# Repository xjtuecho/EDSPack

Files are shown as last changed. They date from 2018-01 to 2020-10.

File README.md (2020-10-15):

[English User Manual](UserManual_EN.md)

[English Release Notes](ReleaseNotes_EN.md)

# PDF用户手册下载

- [EDSPack用户手册v18.10.31](DOC/EDSPack用户手册v18.10.31.pdf)

- [STOPack用户手册v19.1.22](DOC/STOPack用户手册v19.1.22.pdf)

# EDSPack用户手册

EDSPack是一款电池组模块，可以用于OWON的一系列示波器，包括但不限于EDS102CV、
SDS7102等型号。EDSPack可以方便地更换18650电池，更换电池无需焊接。EDSPack
本身具备完善的保护和均衡功能，可以最大限度提高电池循环寿命。

## 参数与接口

### 基本参数

基本参数见下表：

| 指标 | 说明 | 备注  |
|:---:|:---:|:-----:|
| 电池安装位置 | 4 | |
| 电池连接方式 | 2串2并 | |
| 电压 | 7.4V | |
| 充电限制电压 | 8.4V | |
| 保护方案 | HY2120CB | 宏康  |
| 均衡方案 | HY2213-BB3A | 宏康  |

### 端子布局

主板端子布局和实物图见下图：

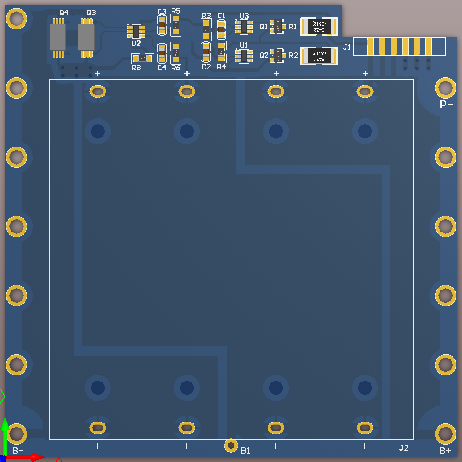
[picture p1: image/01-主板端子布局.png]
主板端子布局


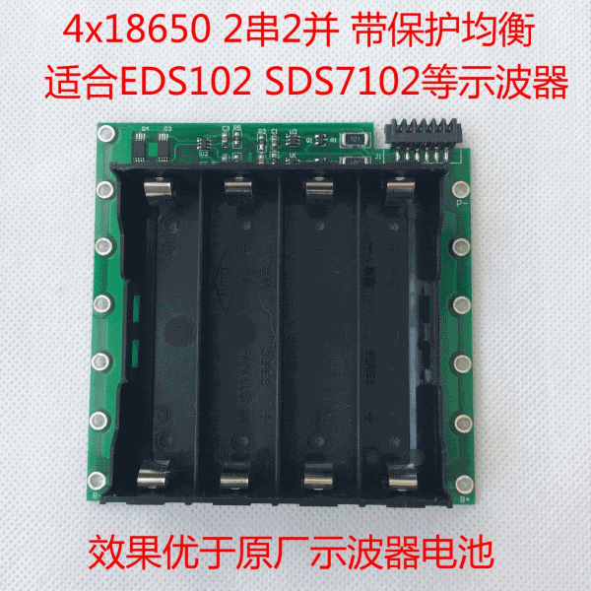
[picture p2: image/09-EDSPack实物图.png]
EDSPack实物图


### 端子说明

端子与主要器件见下表:

| 端子号 | 功能 | 备注 |
|:---:|:---:|:---:|
| J1 | 示波器连接端子 | 6P 2.5mm间距 |
| B1-B4 | 电池座 | 均为上正下负 |
| B+ | 电池组正极 | |
| B- | 电池组负极 | |
| P- | 经过保护电路以后的负极 | |

## 使用指南

### 电池选择与安装

EDSPack可以安装4节18650电池，4节电池两串两并，B1与B2并联，B3与B4并联。

电池安装之前，需要保证4节电池电压相同，可以使用万用表检查电池电压。
如果电压不同建议使用同一个充电器将4节电池电量充满，然后依次装入。

注意：

 1. 电池装入时，一定注意正负极，电池正极全部朝向芯片，电池接反可能导致设备
    损坏，火灾等严重的后果。
 2. 电池首次装入以后，EDSPack默认处于放电保护状态，需要充一下电激活，该现象
    为保护电路的正常逻辑。

EDSPack可以兼容多种18650电池：

- 追求大容量可以选择4节松下NCR18650B 3400mAh电池，电池组容量6800mAh,7.4V
- 或者4节LGABF1L1865,3350mAh电池，电池组容量6700mAh，7.4V
- 或者4节LGDBMJ11865-3500mAh电池，电池组容量7000mAh，7.4V
- 追求性价比可以选择4节三星2600mAh电池，电池组容量5200mAh，7.4V
- 追求更好的性价比可以选择国产电池或者拆机电池，使用拆机电池需要具备电池容量
  测试能力，务必选择4节**相同品牌容量接近**的电池。

### 示波器安装

示波器安装以EDS102C为例。

将示波器底部电池仓盖取下，示波器屏幕朝下，放置到软台面上（如床沙发等），
保护示波器正面旋钮与按键。

将EDSPack装入电池后推入示波器电池仓，注意保持EDSPack与电池仓左右缝隙接近。

EDSPack完全推入以后，顶部仍然有一定空间，塞入一张约10x10cm的厚纸板，保证EDSPack
不会上下晃动，装入以后效果见下图：

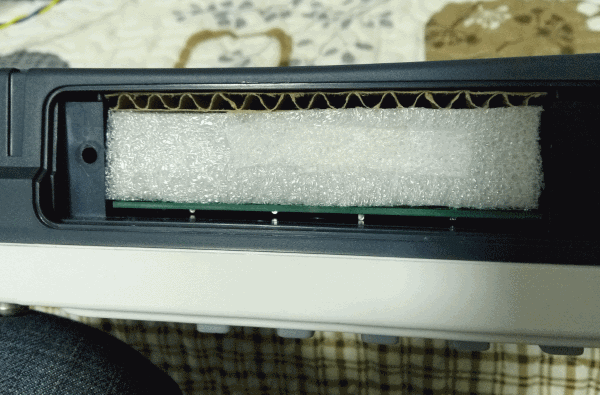
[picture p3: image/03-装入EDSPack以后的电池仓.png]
装入EDSPack以后的电池仓


使用柔软物体，如泡沫，填充EDSPack与示波器电池盖板之间的空隙，将示波器电池仓盖板装上。

EDSPack如果没有激活，将示波器交流电源线插入，连接市电即可激活电池组。

### 连线使用

EDSPack也可以使用于其它需要7.4V电池组供电的场合。

通过B+和B-焊盘焊线，直接从7.4V电池组取电，不经过保护板，保护电路失效，
均衡电路依然生效。

通过B+和P-焊盘焊线，经过保护板，保护电路与均衡电路均生效。实际上J1端子
连接B+和P-两个焊盘网络。

## 性能测试

### 电流测试

以EDS102CV为例，正常工作电流约1.85A。示波器关闭以后，电流约2.3mA，以此可以
估算电池使用时间。

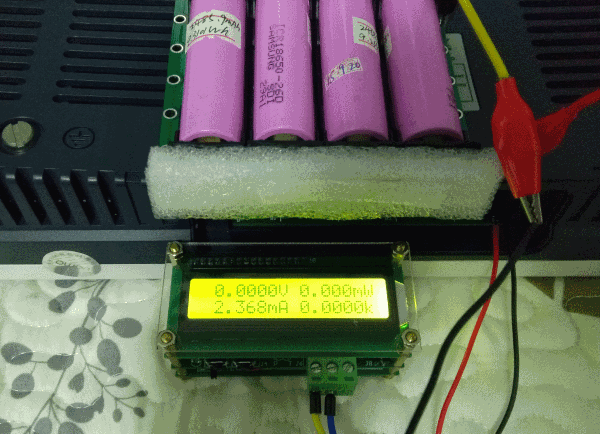
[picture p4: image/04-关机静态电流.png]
关机静态电流


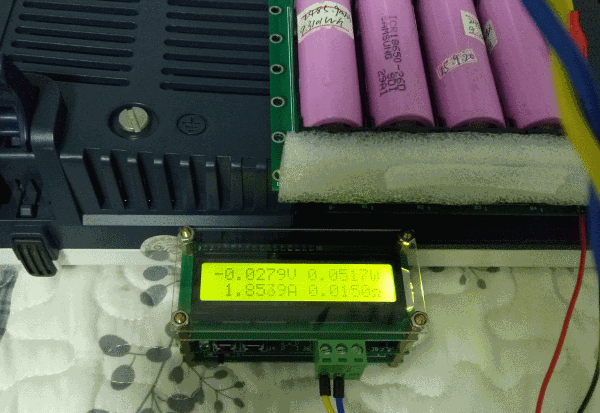
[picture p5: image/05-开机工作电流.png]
开机工作电流


5200mAh电池组正常使用时间为`5.2/1.85=2.8`小时。待机时间为`5200/2.3/24=94`天。

其余电池组容量可以按照此公式计算。

注意：*EDS102CV示波器电池输入静态电流偏大，约2.3mA，长期闲置会将电池组电放光，
隔一段时间需要将示波器充一次电。这是示波器本身的问题，不是电池组的问题*。

### 电压测试

EDSPack在示波器中充满电以后，电压见下图所示：

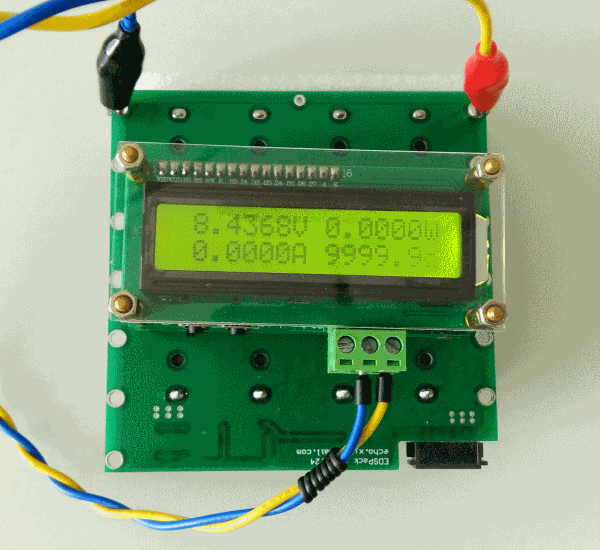
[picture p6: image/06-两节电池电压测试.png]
两节电池电压测试


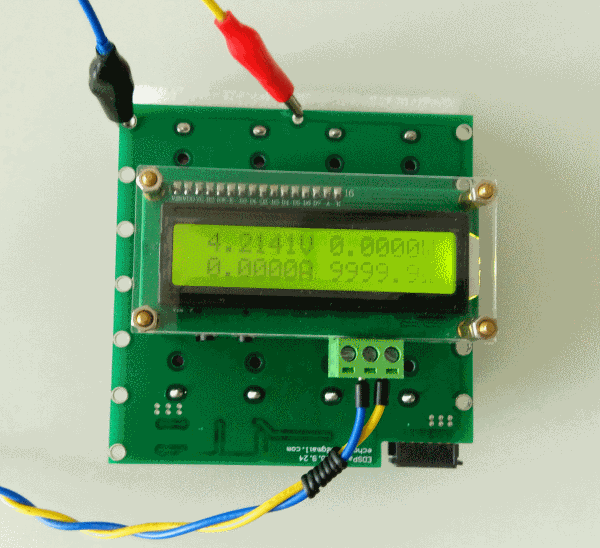
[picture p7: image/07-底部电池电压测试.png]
底部电池电压测试


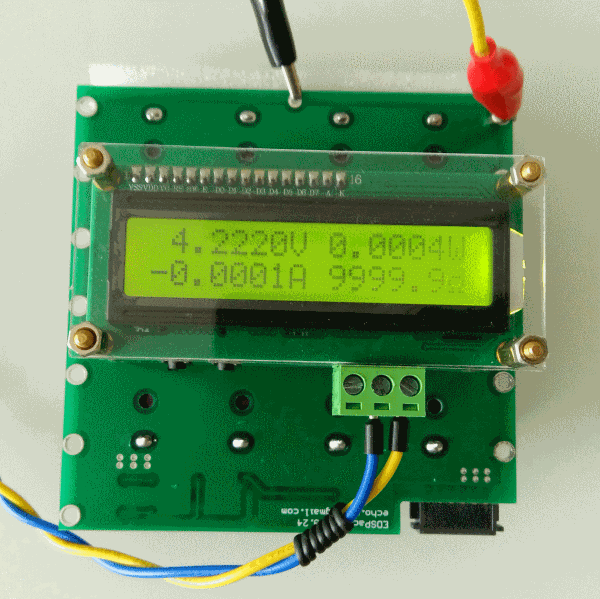
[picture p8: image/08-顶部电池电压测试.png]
顶部电池电压测试


## 3D打印外壳

该外壳来自网友`Matthew Pearce <mpea413@aucklanduni.ac.nz>`，使用Solicworks设计，可直接打印。

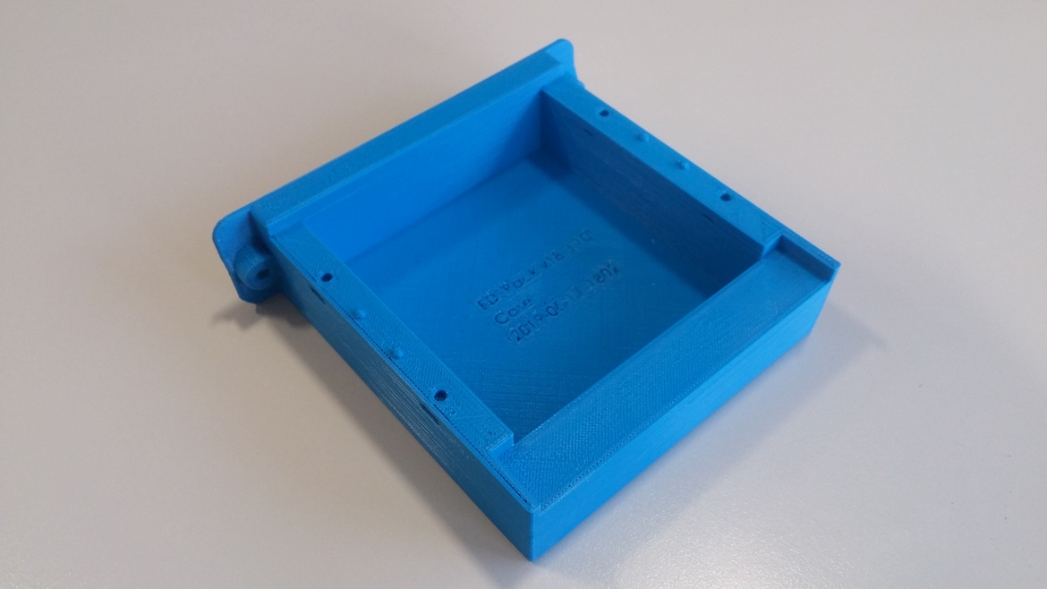
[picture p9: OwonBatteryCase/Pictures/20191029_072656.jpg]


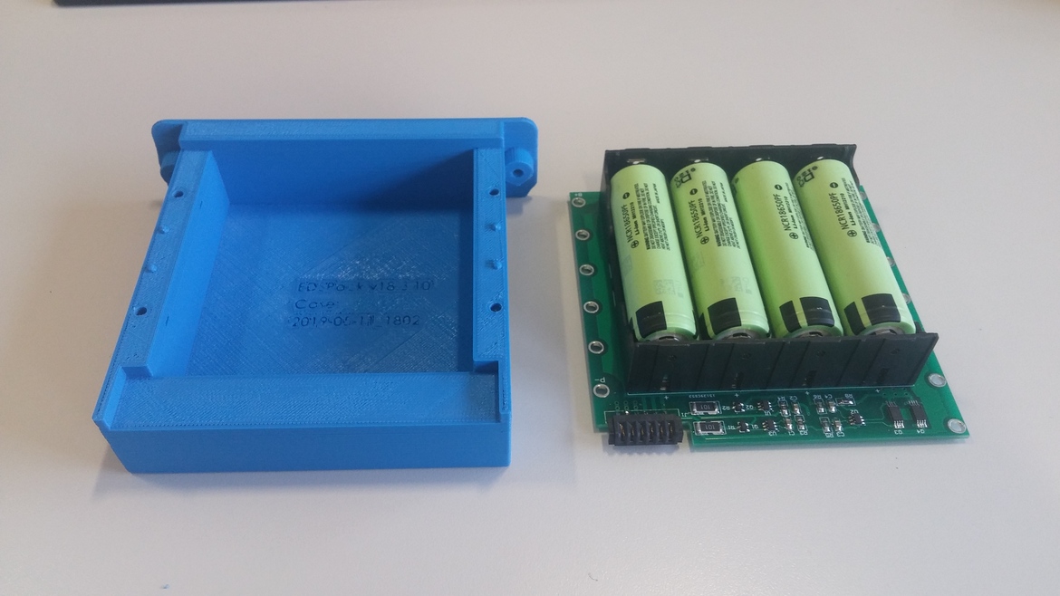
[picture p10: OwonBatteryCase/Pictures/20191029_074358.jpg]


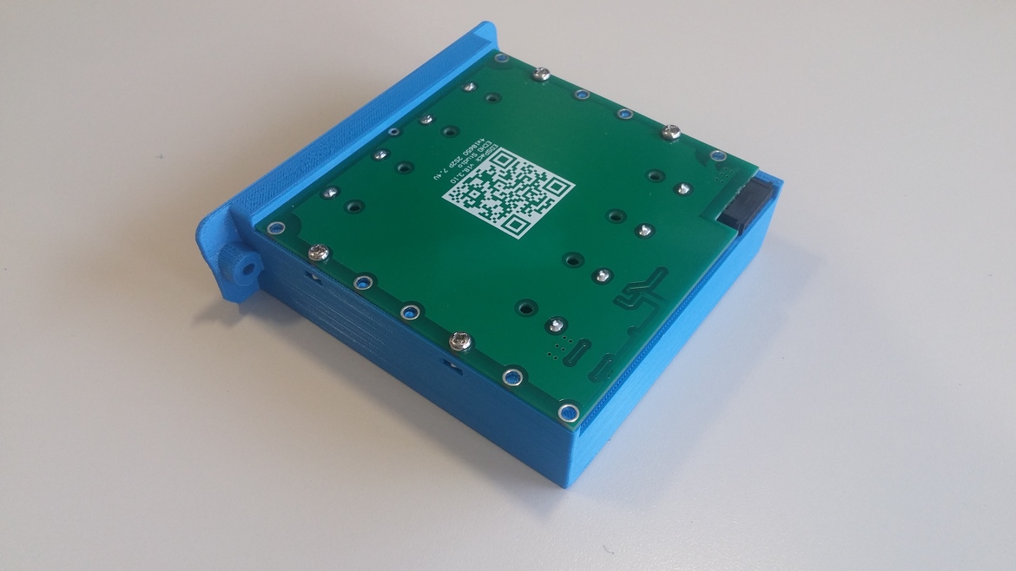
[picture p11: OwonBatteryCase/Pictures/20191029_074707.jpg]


[设计文件下载](OwonBatteryCase)

## 更多信息

[发布日志](ReleaseNotes.md)

[购买链接](https://item.taobao.com/item.htm?spm=a1z10.1-c.w4004-9102396040.29.17d11e5fmlPS4n&id=522970098585)

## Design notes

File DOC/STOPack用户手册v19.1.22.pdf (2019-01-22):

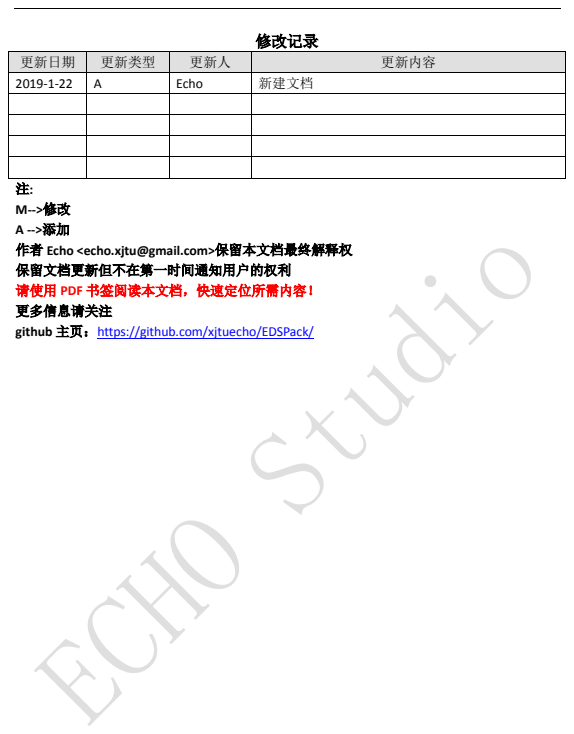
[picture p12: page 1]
修改记录

更新日期 | 更新类型 | 更新人 | 更新内容
2019-1-22 | A | Echo | 新建文档

作者 Echo <echo.xjtu@gmail.com>保留本文档最终解释权
保留文档更新但不在第一时间通知用户的权利
请使用 PDF 书签阅读本文档，快速定位所需内容！
更多信息请关注
github 主页：https://github.com/xjtuecho/EDSPack/

## STOPack 用户手册

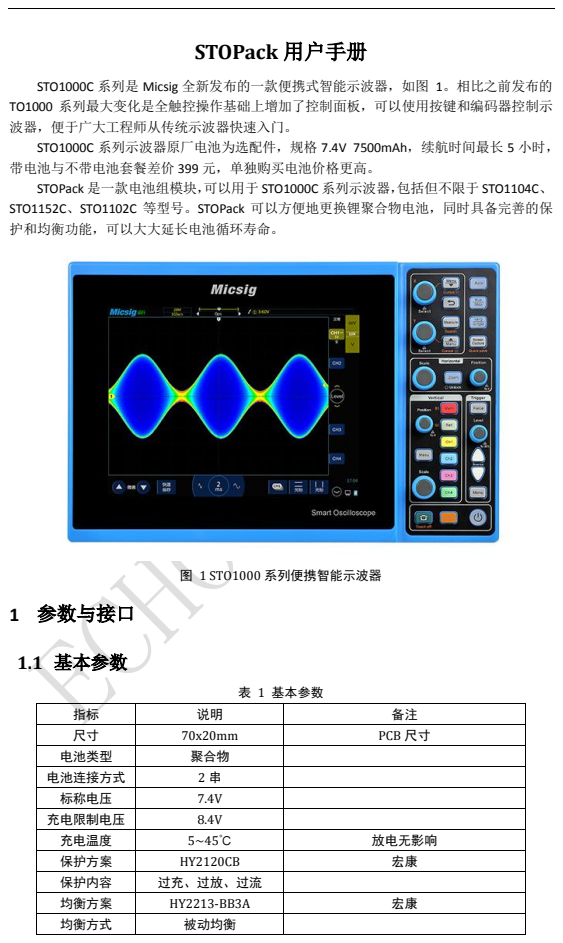
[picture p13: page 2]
图 1 STO1000 系列便携智能示波器; 1 参数与接口; 1.1 基本参数; 表 1 基本参数

STO1000C 系列是 Micsig 全新发布的一款便携式智能示波器，如图 1。相比之前发布的
TO1000 系列最大变化是全触控操作基础上增加了控制面板，可以使用按键和编码器控制示
波器，便于广大工程师从传统示波器快速入门。
STO1000C 系列示波器原厂电池为选配件，规格 7.4V 7500mAh，续航时间最长 5 小时，
带电池与不带电池套餐差价 399 元，单独购买电池价格更高。
STOPack 是一款电池组模块，可以用于 STO1000C 系列示波器，包括但不限于 STO1104C、
STO1152C、STO1102C 等型号。STOPack 可以方便地更换锂聚合物电池，同时具备完善的保
护和均衡功能，可以大大延长电池循环寿命。

指标 | 说明 | 备注
尺寸 | 70x20mm | PCB 尺寸
电池类型 | 聚合物
电池连接方式 | 2 串
标称电压 | 7.4V
充电限制电压 | 8.4V
充电温度 | 5~45℃ | 放电无影响
保护方案 | HY2120CB | 宏康
保护内容 | 过充、过放、过流
均衡方案 | HY2213-BB3A | 宏康
均衡方式 | 被动均衡

## 1.2 端子布局

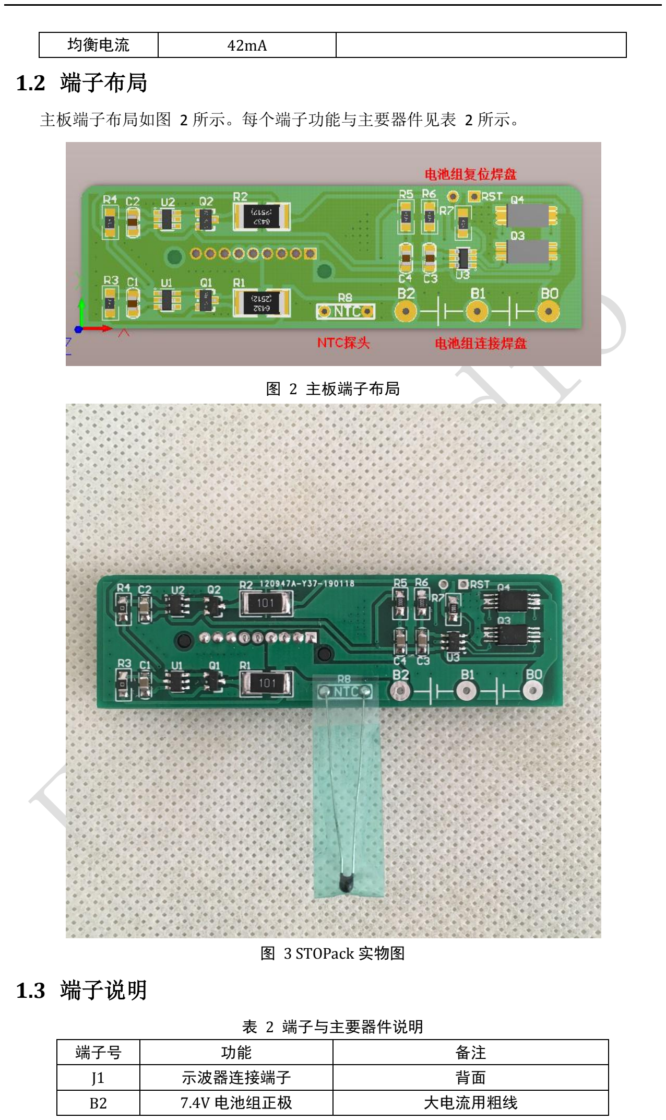
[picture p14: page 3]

主板端子布局如图 2 所示。每个端子功能与主要器件见表 2 所示。

图 2 主板端子布局

图 3 STOPack 实物图

## 1.3 端子说明

表 2 端子与主要器件说明

均衡电流 | 42mA
端子号 | 功能 | 备注
J1 | 示波器连接端子 | 背面
B2 | 7.4V 电池组正极 | 大电流用粗线

## 2 使用指南

## 2.1 电池选择

与 18650 锂电池不同，锂聚合物电池并没有标准的尺寸，厂商一般用“厚宽长”编码表 示电池的尺寸，如 4858102 编码表示电池厚度 4.8mm，宽度 58mm，长度 102mm，注意厚 度单位一般为 0.1mm，宽度和长度单位为 mm。
STO1000C 的电池仓尺寸约为 10x70x200mm，除去 STOPack 宽度 20mm，并预留 10mm 接线空间，实际可以利用的体积为 10x70x170mm，考虑 NTC 探头的位置，两块电池上下布 局比较合适，因此单块电池的体积大约 5x70x170mm，实际使用电池的尺寸厚宽长都必须在 这个体积范围内。
由于两节电池串联使用，需要两节电池参数上尽可能接近，要求同厂商、同品牌、同容 量、同电压。国内聚合物电池货源十分繁杂，大容量聚合物电池一般为平板电脑或者移动电 源生产，有实力的厂商如 ATL、LISHEN 等的产品很少在零售市场见到。官方电池 7500mAh 充分利用了电池仓体积，零售市场上能买到的聚合物电池容量要小一些。可以按照体积编码 在电商网站搜索。
推荐使用小米移动电源高配版 10000mAh（型号 PLM01ZM 或 PLM03ZM）的拆机电池， 型号 M54，原因如下：
1）体积 4.8x58x102mm，两片叠放体积 9.6x58x102mm，完全放得下。 2）容量适中，标称 5000mAh，19.2Wh。
3）供应商为 ATL、LISHEN，大品牌品质有保证。 4）两块电池一直并联使用，电池一致性好。
5）货源充足，成本低廉。
使用拆机 M54 电池主要缺点是电池仓体积利用不充分，尤其是长度浪费很多，而且 4.4V 高压电池只用到 4.2V，容量会有折扣。另一方面，锂电池不适合满电存放，4.4V 高压电池 只用到 4.2V 对延长电池寿命有好处。
您也可以自行摸索更合适的电池尺寸，一般情况下锂电池体积越大容量越大，但是电池 的三个维度都要在限定的尺寸范围内。如果有更合适的聚合物电池，请告诉我。

## 2.2 电池安装与复位

将两片电池串联，引出中线，中线接入 STOPack 的 B1 焊盘。电池正极接入 B2 焊盘，电 池负极接入 B0 焊盘。使用烙铁直接焊接，注意保持 STOPack 焊盘背面平整，去除多余的锡。 注意由于 STOPack 自带了保护与均衡电路，需要去掉聚合物电池自带保护板。去掉保护 板以后焊接时一定注意安全。不要短路!不要短路!不要短路！ 电池首次接入以后，STOPack 默认处于放电保护状态，需要充一下电激活。或者用镊子 短路 RST 焊盘来复位电池。该现象为保护电路的正常逻辑。

B1 | 7.4V 电池组中点 | 小电流
B0 | 7.4V 电池组负极 | 大电流用粗线
RST | 保护芯片复位焊盘 | 短接 RST 左侧两个焊盘复位
NTC | 温度保护电阻 | 尽量靠近电池

## 2.3 示波器安装

以 STO1104C 为例：
将示波器底部电池仓盖取下，示波器屏幕朝下，放置到软台面上（如床、沙发等），保 护示波器正面旋钮与按键。
用烙铁将 STOPack 背面焊盘焊平，保证 STOPack 的背面光滑，不要有凸起。将 STOPack 和电池装入电池仓，稍微用力将 STOPack 压紧，如图 4 所示。电池可通过泡沫双面胶来辅 助固定，双面胶够用就好，不要太多，避免给以后更换电池造成麻烦。
NTC 尽量靠近电池。

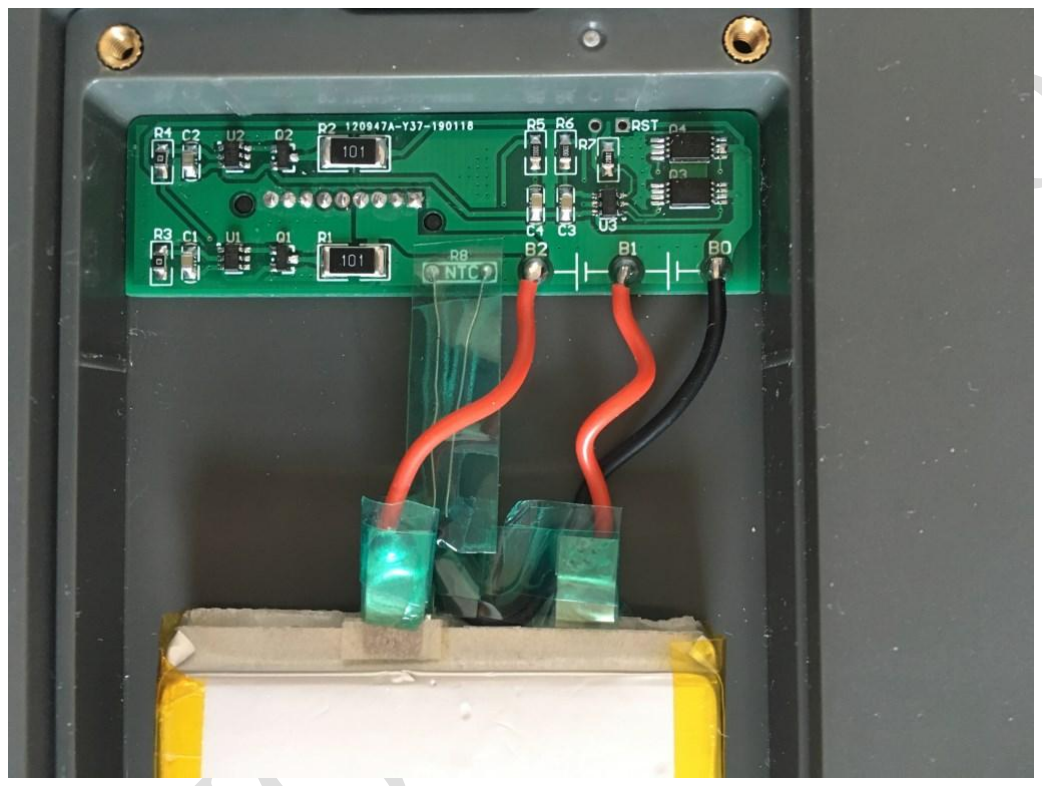
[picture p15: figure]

图 4 将 STOPack 和电池装入电池仓
使用柔软物体，如泡沫，填充示波器电池仓的剩余空间，如图 5，STOPack 电路板上部 也需要填充，保证有一定的压力，辅助电路板固定。

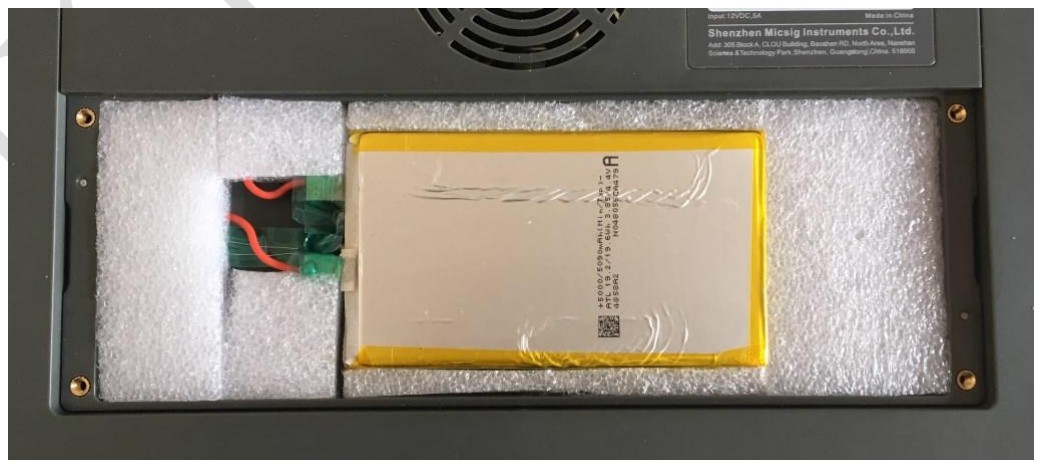
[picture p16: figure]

图 5 填充电池仓剩余空间
安装电池仓盖，如图 6。如按开机键无反映，需要激活 STOPack，将示波器交流电源接 入充一下电即可激活 STOPack。

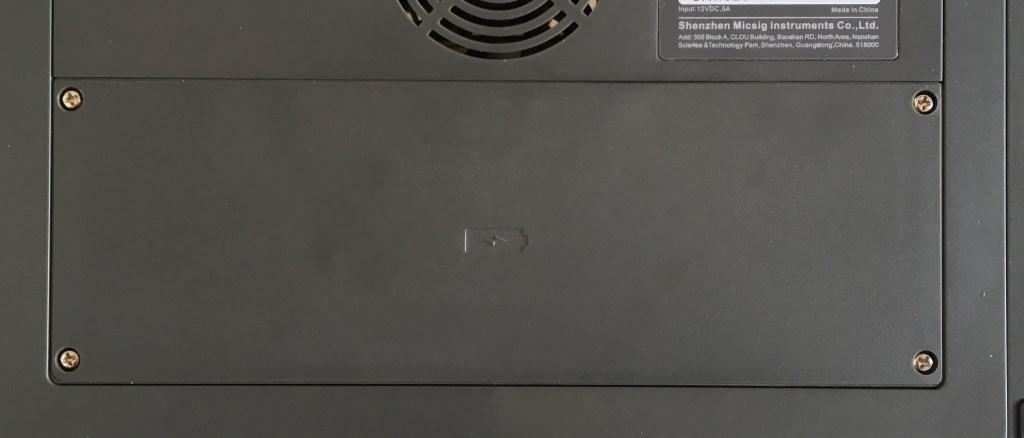
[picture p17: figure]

图 6 安装电池仓盖

## 3 续航时间

以 STO1104C 为例，正常工作电流约 1.25A。示波器关闭以后，静态电流约 0.272mA， 见图 7 图 8。以此可以估算电池使用时间。
以 5000mAh电池组为例：正常使用时间为 5/1.25=4小时。待机时间为5000/0.272/24=766 天。其余电池组容量可以按照此公式计算。
实测使用 M54 拆机电池，STO1104C 续航时间 3 小时多一点。

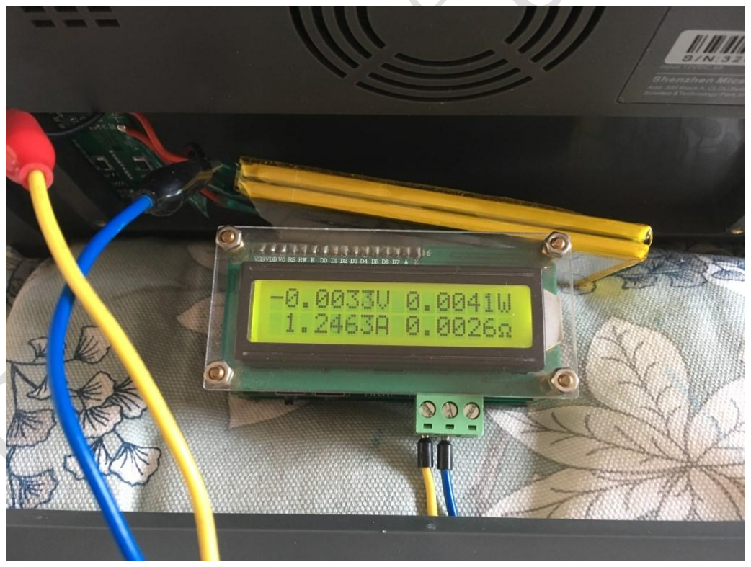
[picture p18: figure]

图 7 开机工作电流

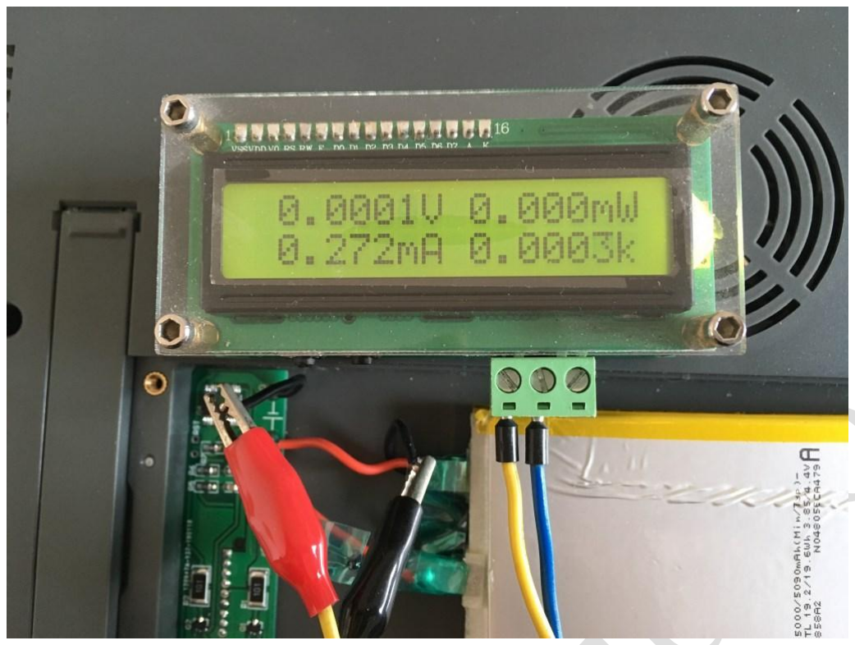
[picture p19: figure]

图 8 关机静态电流

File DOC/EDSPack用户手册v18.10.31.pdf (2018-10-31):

修改记录
更新日期 | 更新类型 | 更新人 | 更新内容
2015-9-25 | A | Echo | 新建文档
2015-10-11 | A | Echo | 完成文档
2018-10-31 | M | Echo | 根据最新硬件版本更新手册

注:
M-->修改
A -->添加
作者 Echo <echo.xjtu@gmail.com>保留本文档最终解释权，保留文档更新但不在第一时间通 知用户的权利

## EDSPack 用户手册

EDSPack是一款电池组模块，可以用于OWON的一系列示波器，包括但不限于EDS102CV、 SDS7102 等型号。EDSPack 可以方便地更换 18650 电池，更换电池无需焊接。EDSPack 本身 具备完善的保护和均衡功能，可以最大限度提高电池循环寿命。

## 1 参数与接口

## 1.1 基本参数

表 1 基本参数

## 1.2 端子布局

主板端子布局如图 1 所示。每个端子功能与主要器件见表 2 所示。

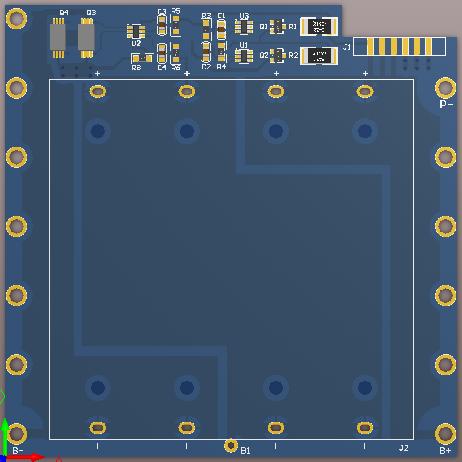
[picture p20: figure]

图 1 主板端子布局

指标 | 说明 | 备注
电池安装位置 | 4
电池连接方式 | 2 串 2 并
电压 | 7.4V
充电限制电压 | 8.4V
保护方案 | HY2120CB | 宏康
均衡方案 | HY2213-BB3A | 宏康

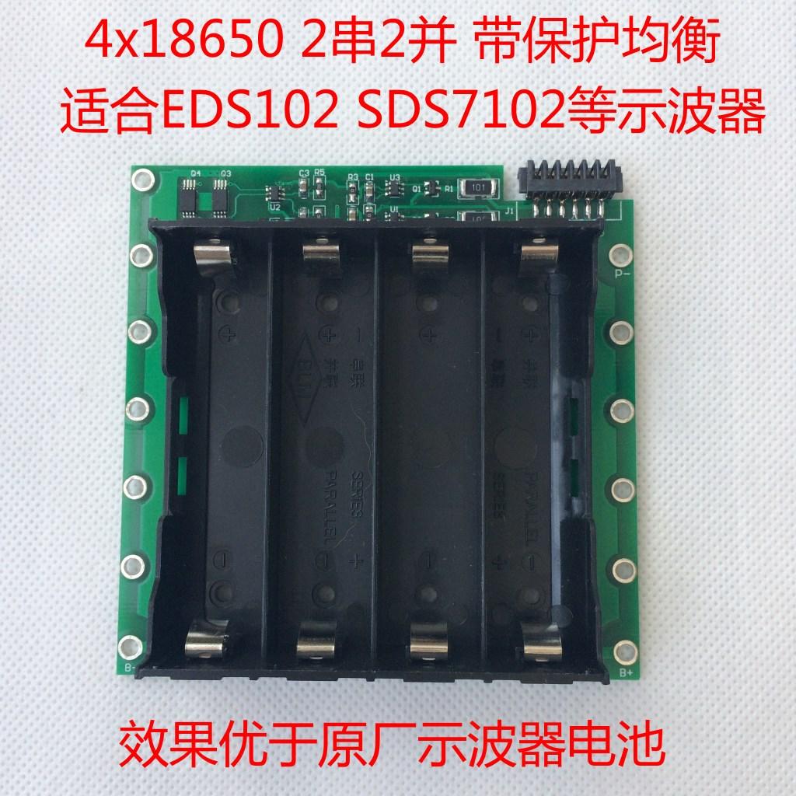
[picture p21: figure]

图 2 EDSPack 实物图

## 1.3 端子说明

表 2 端子与主要器件说明

## 2 使用指南

## 2.1 电池选择与安装

EDSPack 可以安装 4 节 18650 电池，4 节电池两串两并，B1 与 B2 并联，B3 与 B4 并联。 电池安装之前，需要保证 4 节电池电压相同，可以使用万用表检查电池电压。如果电压 不同建议使用同一个充电器将 4 节电池电量充满，然后依次装入。
注意：
1） 电池装入时，一定注意正负极，电池正极全部朝向芯片，电池接反可能导致设备损 坏，火灾等严重的后果。
2） 电池首次装入以后，EDSPack 默认处于放电保护状态，需要充一下电激活，该现象 为保护电路的正常逻辑。
EDSPack 可以兼容多种 18650 电池。
追求大容量可以选择 4 节松下 NCR18650B 3400mAh 电池，电池组容量 6800mAh@7.4V
端子号 | 功能 | 备注
J1 | 示波器连接端子 | 6P 2.5mm 间距
B1-B4 | 电池座 | 均为上正下负
B+ | 电池组正极
B- | 电池组负极
P- | 经过保护电路以后的负极

或者 4 节 LGABF1L1865 3350mAh 电池，电池组容量 6700mAh@7.4V
或者 4 节 LGDBMJ11865 3500mAh 电池，电池组容量 7000mAh@7.4V
追求性价比可以选择 4 节三星 2600mAh 电池，电池组容量 5200mAh@7.4V 追求更好的性价比可以选择国产电池或者拆机电池，使用拆机电池需要具备电池容量测 试能力，务必选择 4 节相同品牌容量接近的电池。

## 2.2 示波器安装

示波器安装以 EDS102C 为例。
将示波器底部电池仓盖取下，示波器屏幕朝下，放置到软台面上（如床沙发等），保护 示波器正面旋钮与按键。
将 EDSPack 装入电池后推入示波器电池仓，注意保持 EDSPack 与电池仓左右缝隙接近。 EDSPack 完全推入以后，顶部仍然有一定空间，塞入一张约 10x10cm 的厚纸板，保证 EDSPack 不会上下晃动，装入以后见图 3 所示。
使用柔软物体，如泡沫，填充 EDSPack 与示波器电池盖板之间的空隙，将示波器电池仓 盖板装上。
EDSPack 如果没有激活，将示波器交流电源线插入，连接市电即可激活电池组。

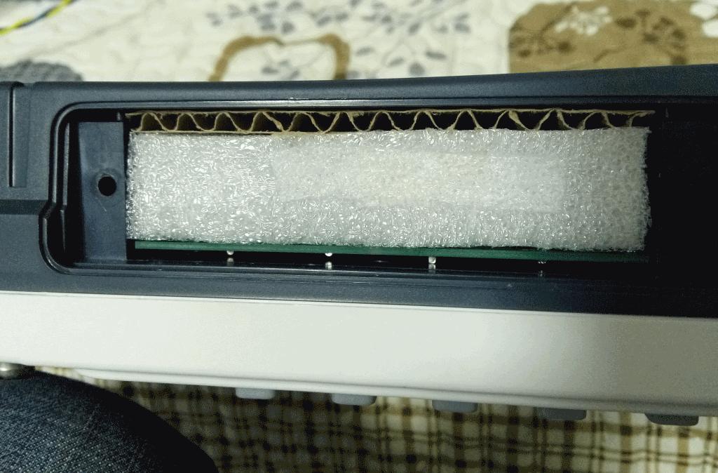
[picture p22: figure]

图 3 装入 EDSPack 以后的电池仓

## 2.3 连线使用

EDSPack 也可以使用于其它需要 7.4V 电池组供电的场合。
通过 B+和 B-焊盘焊线，直接从 7.4V 电池组取电，不经过保护板，保护电路失效，均衡 电路依然生效。
通过 B+和 P-焊盘焊线，经过保护板，保护电路与均衡电路均生效。实际上 J1 端子连接 B+和 P-两个焊盘网络。

## 3 性能测试

## 3.1 电流测试

以 EDS102CV 为例，正常工作电流约 1.85A。示波器关闭以后，电流约 2.3mA，见图 4

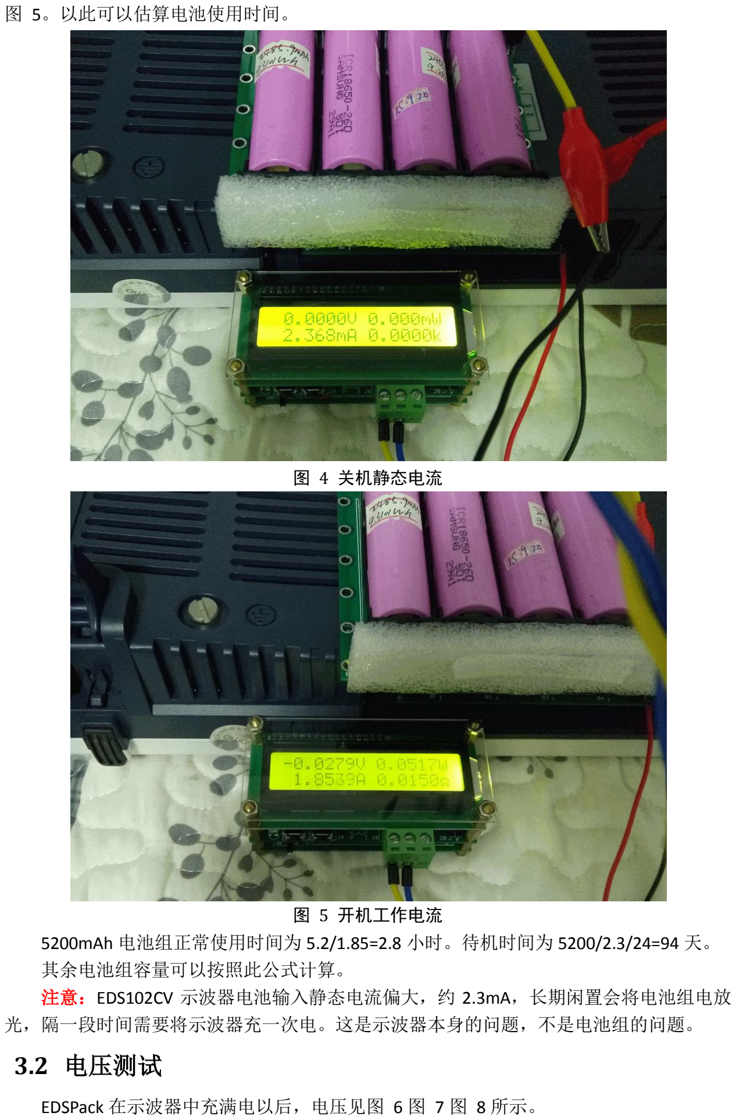
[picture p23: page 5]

图 5。以此可以估算电池使用时间。

图 4 关机静态电流

图 5 开机工作电流
5200mAh 电池组正常使用时间为 5.2/1.85=2.8 小时。待机时间为 5200/2.3/24=94 天。 其余电池组容量可以按照此公式计算。
注意：EDS102CV 示波器电池输入静态电流偏大，约 2.3mA，长期闲置会将电池组电放 光，隔一段时间需要将示波器充一次电。这是示波器本身的问题，不是电池组的问题。

## 3.2 电压测试

EDSPack 在示波器中充满电以后，电压见图 6 图 7 图 8 所示。

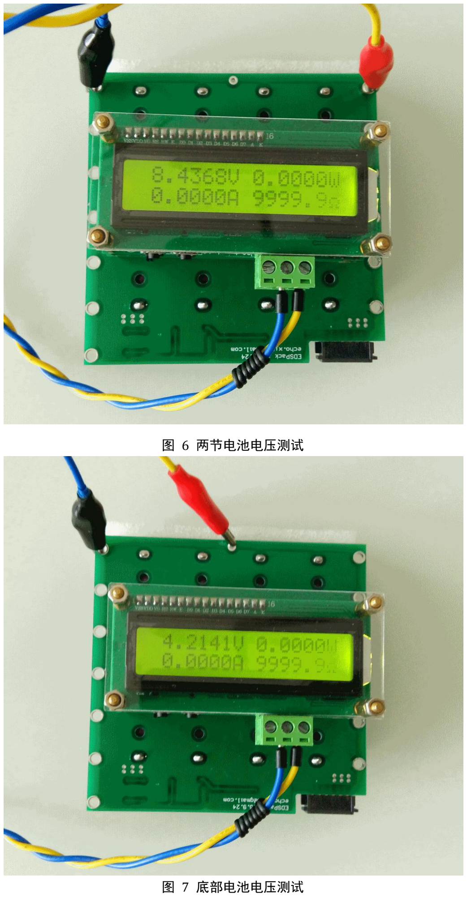
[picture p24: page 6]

图 6 两节电池电压测试

图 7 底部电池电压测试

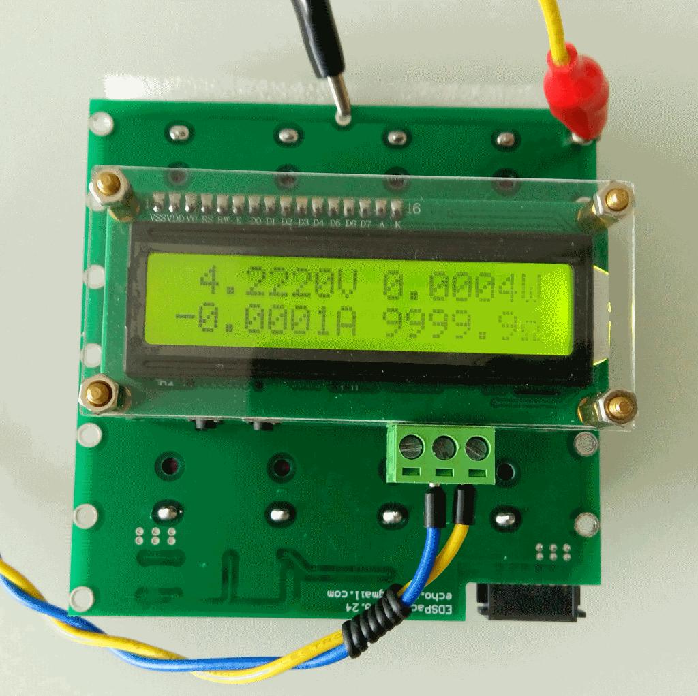
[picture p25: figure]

图 8 顶部电池电压测试

## 4 更多信息

请关注
http://blog.sina.com.cn/xjtuechohttp://weibo.com/eth0
http://shop114445313.taobao.com/

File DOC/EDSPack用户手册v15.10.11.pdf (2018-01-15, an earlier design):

修改记录
更新日期 | 更新类型 | 更新人 | 更新内容
2015-9-25 | A | Echo | 新建文档
2015-10-11 | A | Echo | 完成文档

注:
M-->修改
A -->添加
作者 Echo <echo.xjtu@gmail.com>保留本文档最终解释权，保留文档更新但不在第一时间通 知用户的权利

## EDSPack 用户手册

EDSPack是一款电池组模块，可以用于OWON的一系列示波器，包括但不限于EDS102CV、 SDS7102 等型号。EDSPack 可以方便地更换 18650 电池，更换电池无需焊接。EDSPack 本身 具备完善的保护和均衡功能，可以最大限度提高电池循环寿命。

## 1 参数与接口

## 1.1 基本参数

表 1 基本参数

## 1.2 端子布局

主板端子布局如图 1 所示。每个端子功能与主要器件见表 2 所示。

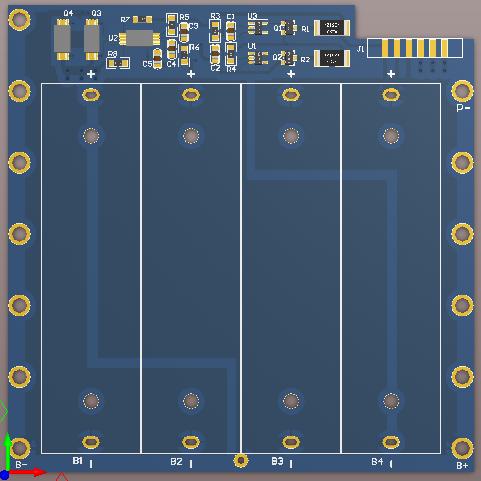
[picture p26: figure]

图 1 主板端子布局

指标 | 说明 | 备注
电池安装位置 | 4
电池连接方式 | 2 串 2 并
电压 | 7.4V
充电限制电压 | 8.4V
保护方案 | FS3332C
均衡方案 | MM3513

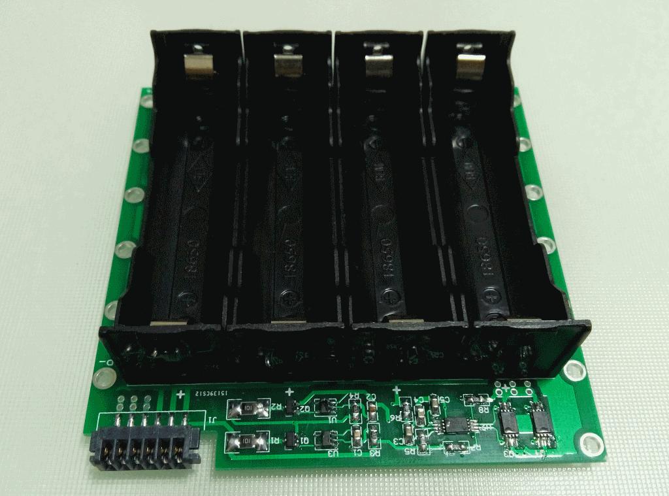
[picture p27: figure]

图 2 EDSPack 实物图

## 1.3 端子说明

表 2 端子与主要器件说明

## 2 使用指南

## 2.1 电池选择与安装

EDSPack 可以安装 4 节 18650 电池，4 节电池两串两并，B1 与 B2 并联，B3 与 B4 并联。 电池安装之前，需要保证 4 节电池电压相同，可以使用万用表检查电池电压。如果电压 不同建议使用同一个充电器将 4 节电池电量充满，然后依次装入。
注意：
1） 电池装入时，一定注意正负极，电池接反可能导致设备损坏，火灾等严重的后果。 2） 电池首次装入以后，EDSPack 默认处于放电保护状态，需要充一下电激活，该现象 为保护电路的正常逻辑。
EDSPack 可以兼容多种 18650 电池。
追求大容量可以选择 4 节松下 NCR18650B 3400mAh 电池，电池组容量 6800mAh@7.4V 或者 4 节 LGABF1L1865 3350mAh 电池，电池组容量 6700mAh@7.4V
或者 4 节 LGDBMJ11865 3500mAh 电池，电池组容量 7000mAh@7.4V
追求性价比可以选择 4 节三星 2600mAh 电池，电池组容量 5200mAh@7.4V 追求更好的性价比可以选择国产电池或者拆机电池，使用拆机电池需要具备电池容量测 试能力，务必选择 4 节相同品牌容量接近的电池。
端子号 | 功能 | 备注
J1 | 示波器连接端子 | 6P 2.5mm 间距
B1-B4 | 电池座 | 均为上正下负
B+ | 电池组正极
B- | 电池组负极
P- | 经过保护电路以后的负极

## 2.2 示波器安装

示波器安装以 EDS102C 为例。
将示波器底部电池仓盖取下，示波器屏幕朝下，放置到软台面上（如床沙发等），保护 示波器正面旋钮与按键。
将 EDSPack 装入电池后推入示波器电池仓，注意保持 EDSPack 与电池仓左右缝隙接近。 EDSPack 完全推入以后，顶部仍然有一定空间，塞入一张约 10x10cm 的厚纸板，保证 EDSPack 不会上下晃动，装入以后见图 3 所示。
使用柔软物体，如泡沫，填充 EDSPack 与示波器电池盖板之间的空隙，将示波器电池仓 盖板装上。
EDSPack 如果没有激活，将示波器交流电源线插入，连接市电即可激活电池组。


图 3 装入 EDSPack 以后的电池仓

## 2.3 连线使用

EDSPack 也可以使用于其它需要 7.4V 电池组供电的场合。
通过 B+和 B-焊盘焊线，直接从 7.4V 电池组取电，不经过保护板，保护电路失效，均衡 电路依然生效。
通过 B+和 P-焊盘焊线，经过保护板，保护电路与均衡电路均生效。实际上 J1 端子连接 B+和 P-两个焊盘网络。

## 3 性能测试

## 3.1 电流测试

以 EDS102CV 为例，正常工作电流约 1.85A。示波器关闭以后，电流约 2.3mA，见图 4 图 5。以此可以估算电池使用时间。

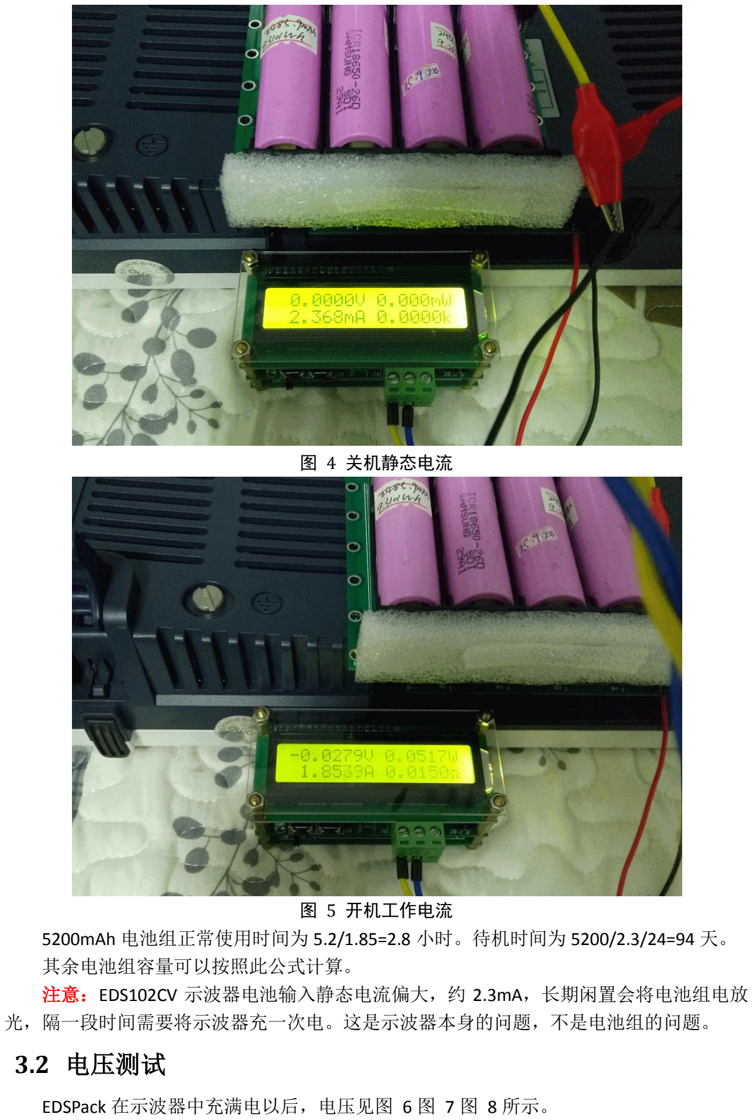
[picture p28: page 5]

图 4 关机静态电流

图 5 开机工作电流
5200mAh 电池组正常使用时间为 5.2/1.85=2.8 小时。待机时间为 5200/2.3/24=94 天。 其余电池组容量可以按照此公式计算。
注意：EDS102CV 示波器电池输入静态电流偏大，约 2.3mA，长期闲置会将电池组电放 光，隔一段时间需要将示波器充一次电。这是示波器本身的问题，不是电池组的问题。

## 3.2 电压测试

EDSPack 在示波器中充满电以后，电压见图 6 图 7 图 8 所示。


图 6 两节电池电压测试

图 7 底部电池电压测试


图 8 顶部电池电压测试

## 4 更多信息

请关注
http://blog.sina.com.cn/xjtuechohttp://weibo.com/eth0
http://shop114445313.taobao.com/

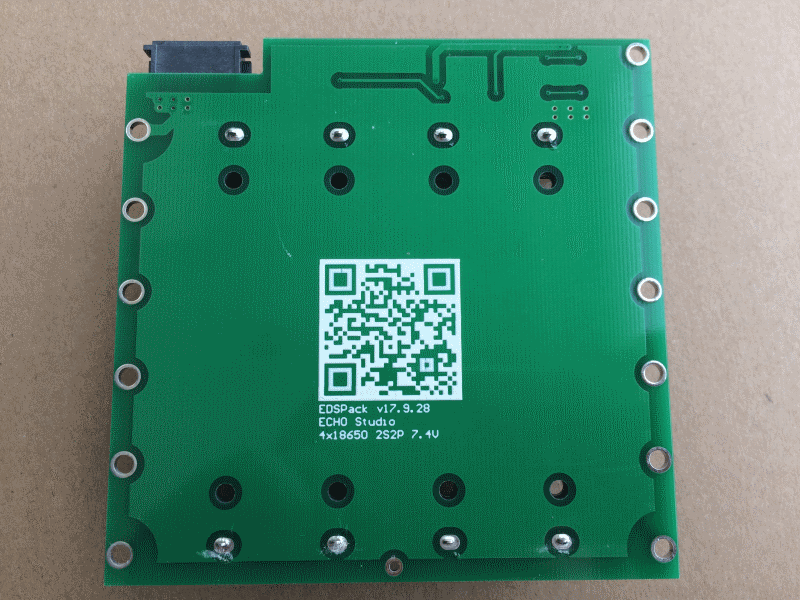
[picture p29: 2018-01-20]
image/10-EDSPack背面.png

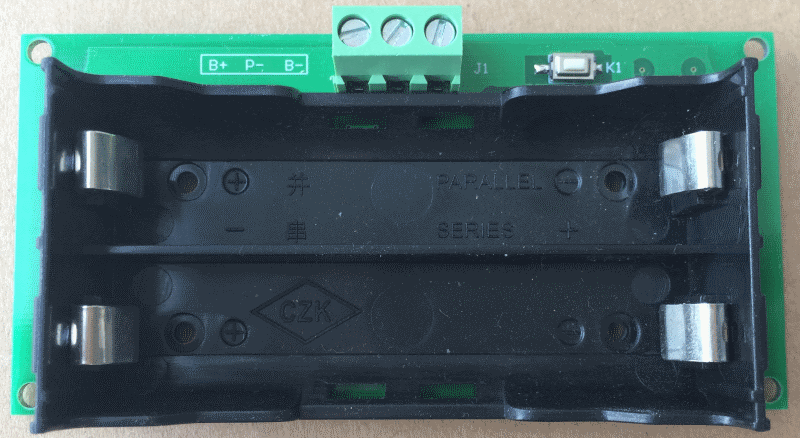
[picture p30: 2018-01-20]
image/11-2SPack正面.png

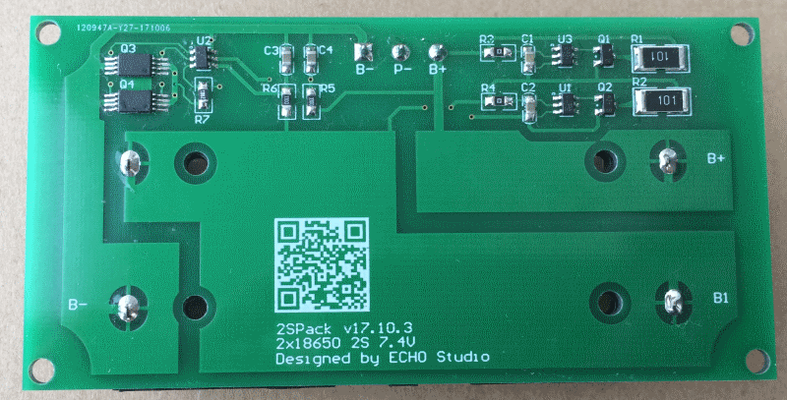
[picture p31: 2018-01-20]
image/12-2SPack背面.png

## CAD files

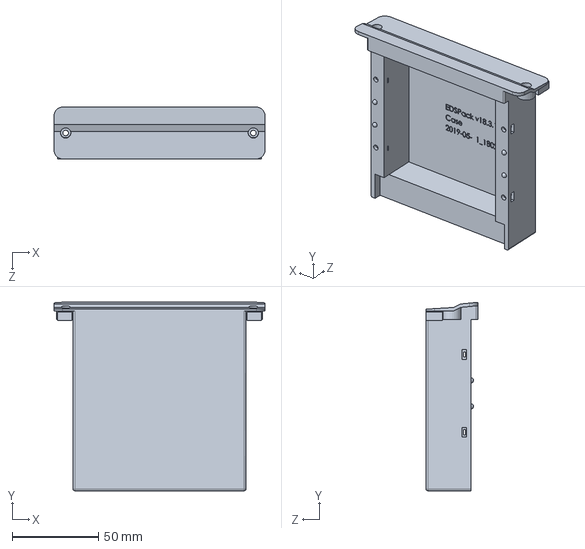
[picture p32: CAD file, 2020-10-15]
OwonBatteryCase/EDSPackV18-3-10_Case_2019-05-11_1802.SLDPRT
122.0 x 109.0 x 30.0 mm

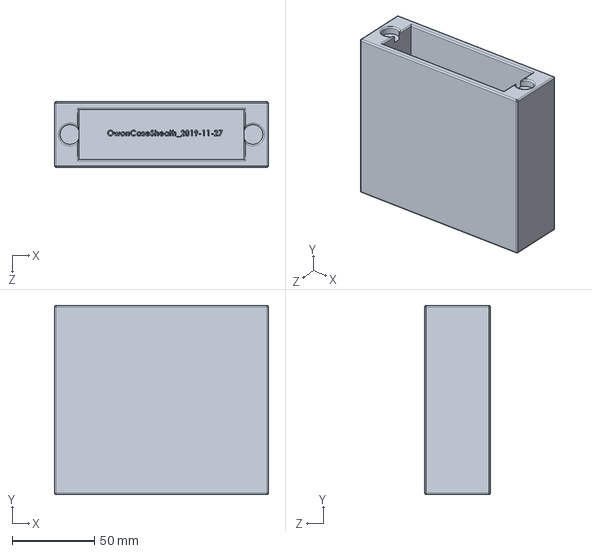
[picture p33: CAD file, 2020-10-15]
OwonBatteryCase/OwonCaseSheath_2019-11-27.SLDPRT
130.0 x 115.0 x 40.0 mm

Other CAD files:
OwonBatteryCase/EDSPackV18-3-10_Case_2019-05-11_1802.STL
OwonBatteryCase/OwonCaseSheath_2019-11-27.STL

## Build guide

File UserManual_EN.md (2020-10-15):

# EDSPack User Manual

EDSPack is a battery pack module for a series of OWON oscilloscope, including
but not limited to EDS102C, SDS7102 etc. Users can replace 18650 batteries on
EDSPack convenient and efficient, and do not need a soldering iron. With excellent
protection and balance feature, EDSPack can extend battery cycling life.

## Parameters and Ports

### Basic Parameters

Please refer to the table below:

| Specs | Description | Notes |
|:---:|:---:|:-----:|
| Battery Cells | 4 | |
| Battery Packs | 2S2P | |
| Nominal Voltage  | 7.4V | |
| Charging Voltage | 8.4V | |
| Protection Scheme| HY2120CB | HYCON |
| Balance Scheme | HY2213-BB3A | HYCON |

### Ports layout

Board ports layout and physical photograph:

Board ports layout

physical photograph

### Ports description

Ports and main components please refer to the table below:

| Port | Function | Notes |
|:---:|:---:|:---:|
| J1 | Osc. power port | 6P 2.5mm |
| B1-B4 | Battery Holder | Top(+) Bottom(-) |
| B+ | Battery+ | |
| B- | Battery- | |
| P- | Battery Pack- | |

## User guide

### Battery selection and install

EDSPack can install four 18650 batteries, two in parallel and two in series.
Before install batteries, you should make sure that the voltages are identical.
You can check the voltage of batteries with multimeter. If the voltages are
different, charge them fully with the same charger, and install them one by one.

Warning:

 1. Battery polarities must be correct, **all 4 battery positive electrode(+) point to chips**.
    Otherwise, serious damage including fire disaster might be caused.
 2. When the battery is first time installed, EDSPack is under protection status,
    short-circuit VM (R8 right) and B-(C5 down) networks or charge EDSPack to
    regain normal status. This is normal feature of protection circuit.

EDSPack is compatible with most 18650 battery.

- In order to get a large capacity, you can chose 4 panasonic NCR18650B 3400mAh, to build a 6800mAh, 7.4V pack.
- Or 4 LG LGABF1L1865, 3350mAh, to build a 6700mAh, 7.4V pack.
- Or 4 LG LGDBMJ11865, 3500mAh, to build a 7000mAh, 7.4V pack.
- In order to get better cost performance, you can chose 4 samsung 2600mAh, to build a 5200mAh, 7.4V pack.
- Or other domestic cheap 18650 even teardown secondhand 18650. Make sure 4 batteries are **same brand same capacity same voltage**.

### Install guide

Take EDS102CV as example:

Tear down the battery cover, put the oscilloscope to a soft surface (bed, sofa, etc),  
then install EDSPack. Insert a 10x10cm thick paper to the top of EDSPack to make
sure it doesn't shake. Refer to the photo below:

After install EDSPack

Use soft stuff such as bubble plastic to fill the space between EDSPack and 
battery cover, then install the battery cover.

If EDSPack is not activated, connect the mains and power on the oscilloscope to activate it.

### Standalone power supply

EDSPack also can be used as a 7.4V standalone power supply.

Drawn out from B+ and B- pads, the protection circuit will be bypass, but the 
balance circuit is still efficient.

Drawn out from B+ and P- pads, both protection and balance circuit are efficient.
In fact, J1 port connects to network of B+ and P- pads.

## Performance test

### Current test

Take EDS102CV for example, the normal working current is about 1.85A. After shutdown, 
the quiescent current is about 2.3mA, then we can estimate the battery life.

Shutdown quiescent current

Power on working current

The normal working time of 5200mAh battery pack is `5.2/1.85=2.8` hours. Standby 
time is about `5200/2.3/24=94` days.

Other battery pack capacities can be calculated in this way.

Warning: *The quiescent current of EDS102CV after shutdown is quite high, about 2.3mA.
A long-time idle may run out of your batteries. You should recharge your oscilloscope
once in a while. This is issue of oscilloscope itself, not battery pack.*.

### Voltage test

When EDSPack is fully charged, voltage test result please refer to photos below:

Two cells in series voltage test

Bottom cells voltage test

Top cells voltage test

## 3D printed case

This case is designed by `Matthew Pearce <mpea413@aucklanduni.ac.nz>` with Solidworks.

3D printed case

3D printed case

3D printed case

[Design file download](OwonBatteryCase)

## More information

[Release Notes](ReleaseNotes_EN.md)

[Purchase at taobao.com](https://item.taobao.com/item.htm?spm=a1z10.1-c.w4004-9102396040.29.17d11e5fmlPS4n&id=522970098585)

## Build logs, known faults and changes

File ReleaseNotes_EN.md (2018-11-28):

## Release Notes

### v18.3.10

- Protection scheme change to HYCON HY2120CB.
- Balance scheme change to HYCON HY2213-BB3A.

### v17.9.28

- Increase insulation distance of B-, B+, P- pads.
- Optimize PCB layout, adjust location of R8 and C5.
- When installing battery for the first time, EDSPack is under protection status,
  short-circuit VM (R8 right) and B-(C5 down) networks to regain normal status.

### v16.2.20

- Change to one 18650x4 battery holder.
- Add QR code.

### v15.9.24

- Initial release. Utilizing four 18650x1 battery holder,
  with protection and balance function, tested OK.

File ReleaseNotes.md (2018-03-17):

## 修订历史

### v18.3.10

- 保护方案更换为宏康HY2120CB
- 均衡方案更换为宏康HY2213-BB3A

### v17.9.28

- 增加B-、B+、P-三个焊盘的绝缘距离。
- 微调PCB布局，调整R8和C5的位置，方便短接。
- 初次装电池时，短接VM（R8右）和B-（C5下）网络可以使电池组进入正常输出状态。

### v16.2.20

- 电池盒更换为1个4节18650电池盒。
- 增加二维码。

### v15.9.24

- 初始版本。使用4个单节18650电池盒，具备保护均衡功能，测试成功。

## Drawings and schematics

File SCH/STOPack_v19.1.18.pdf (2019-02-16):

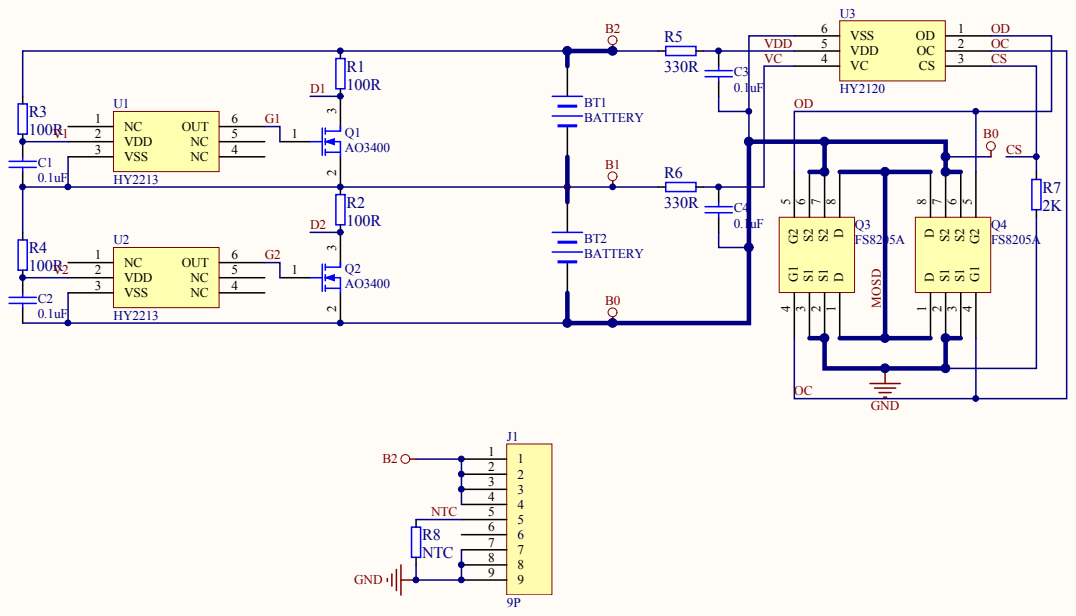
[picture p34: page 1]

VDD VC | 5 | | 2 | OC CS

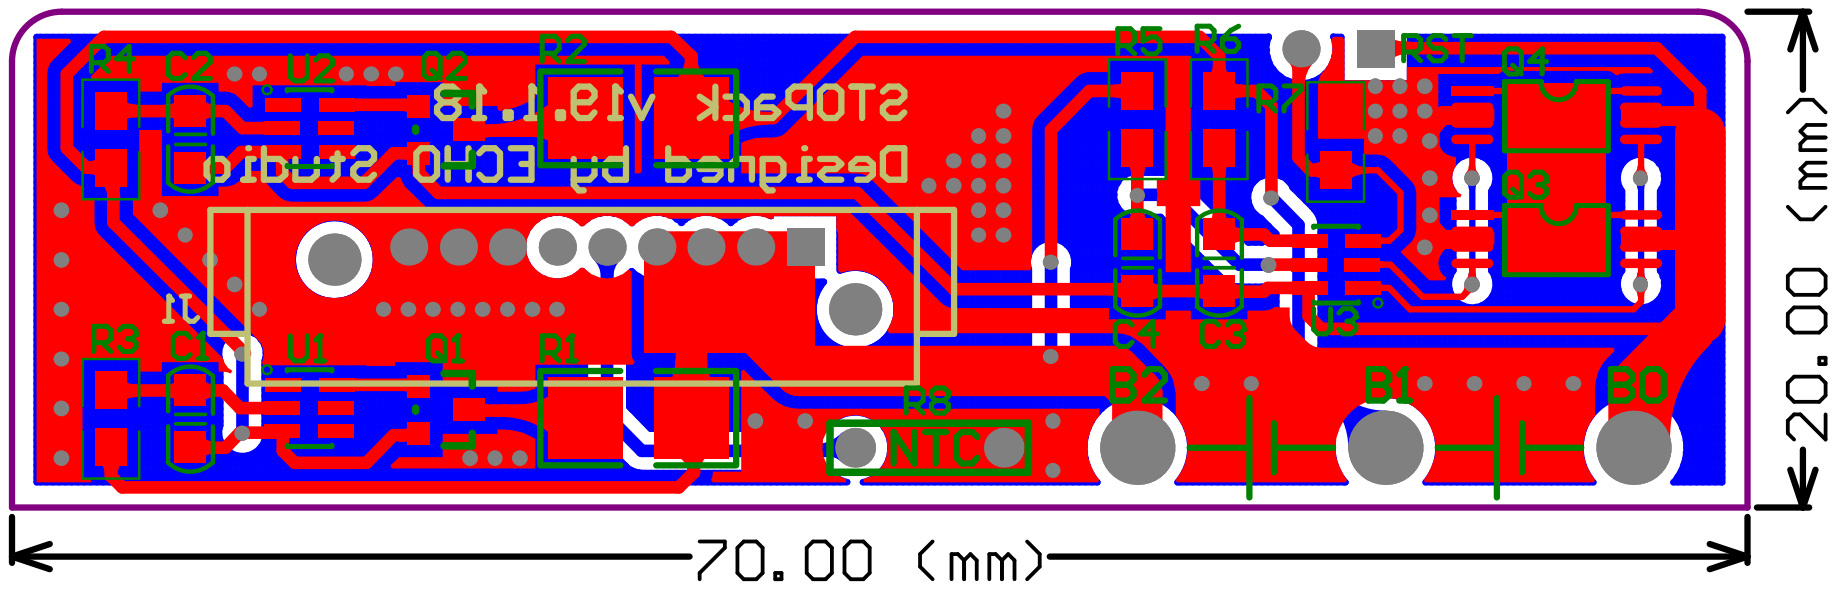
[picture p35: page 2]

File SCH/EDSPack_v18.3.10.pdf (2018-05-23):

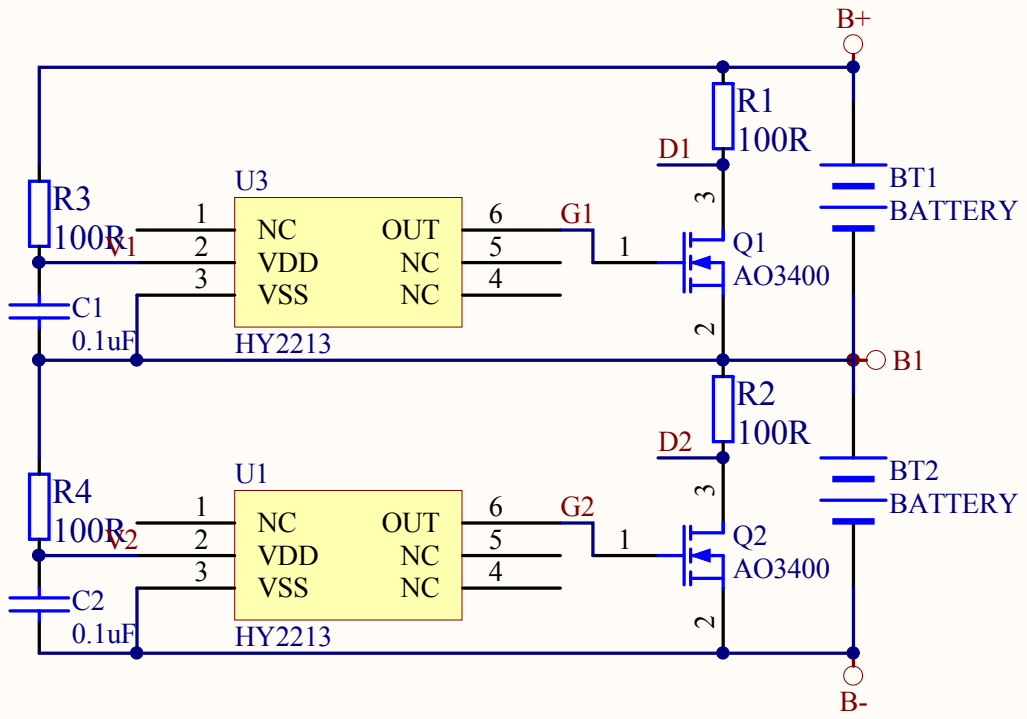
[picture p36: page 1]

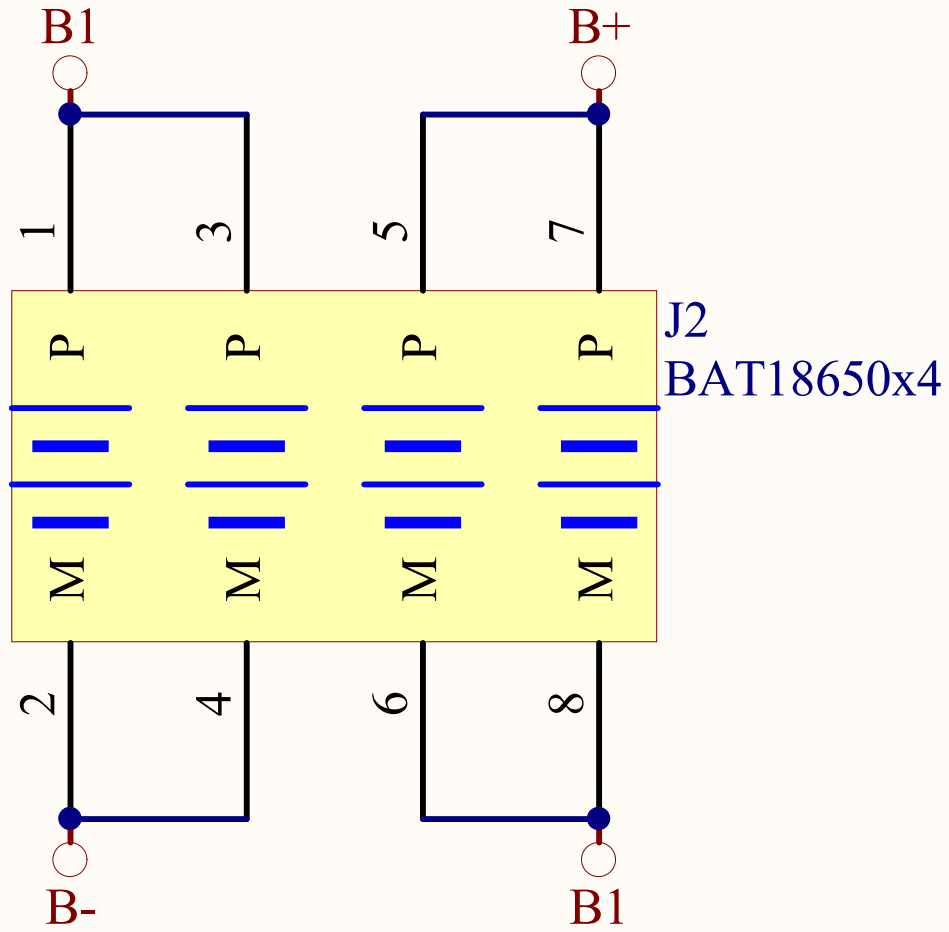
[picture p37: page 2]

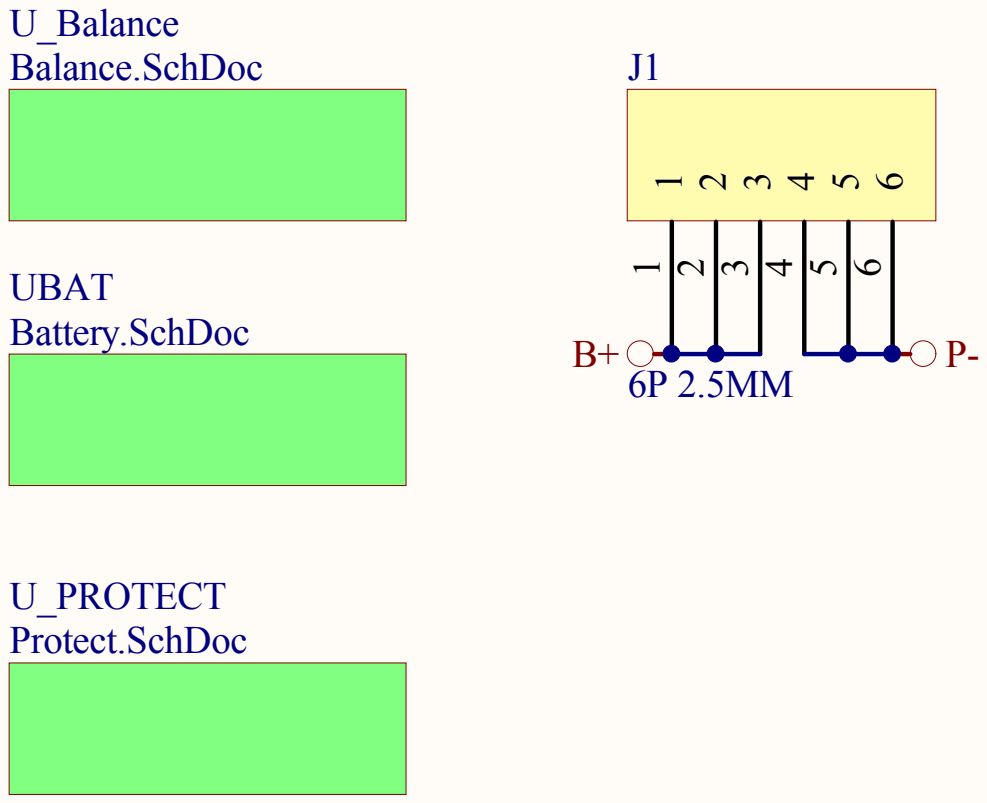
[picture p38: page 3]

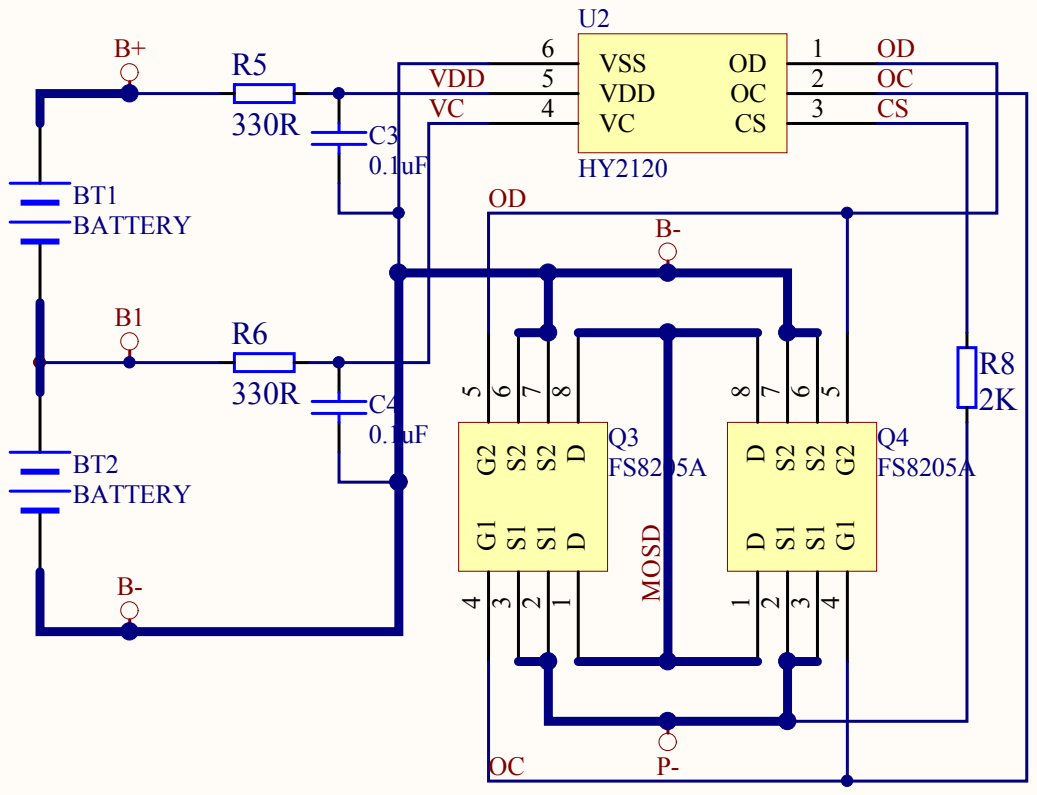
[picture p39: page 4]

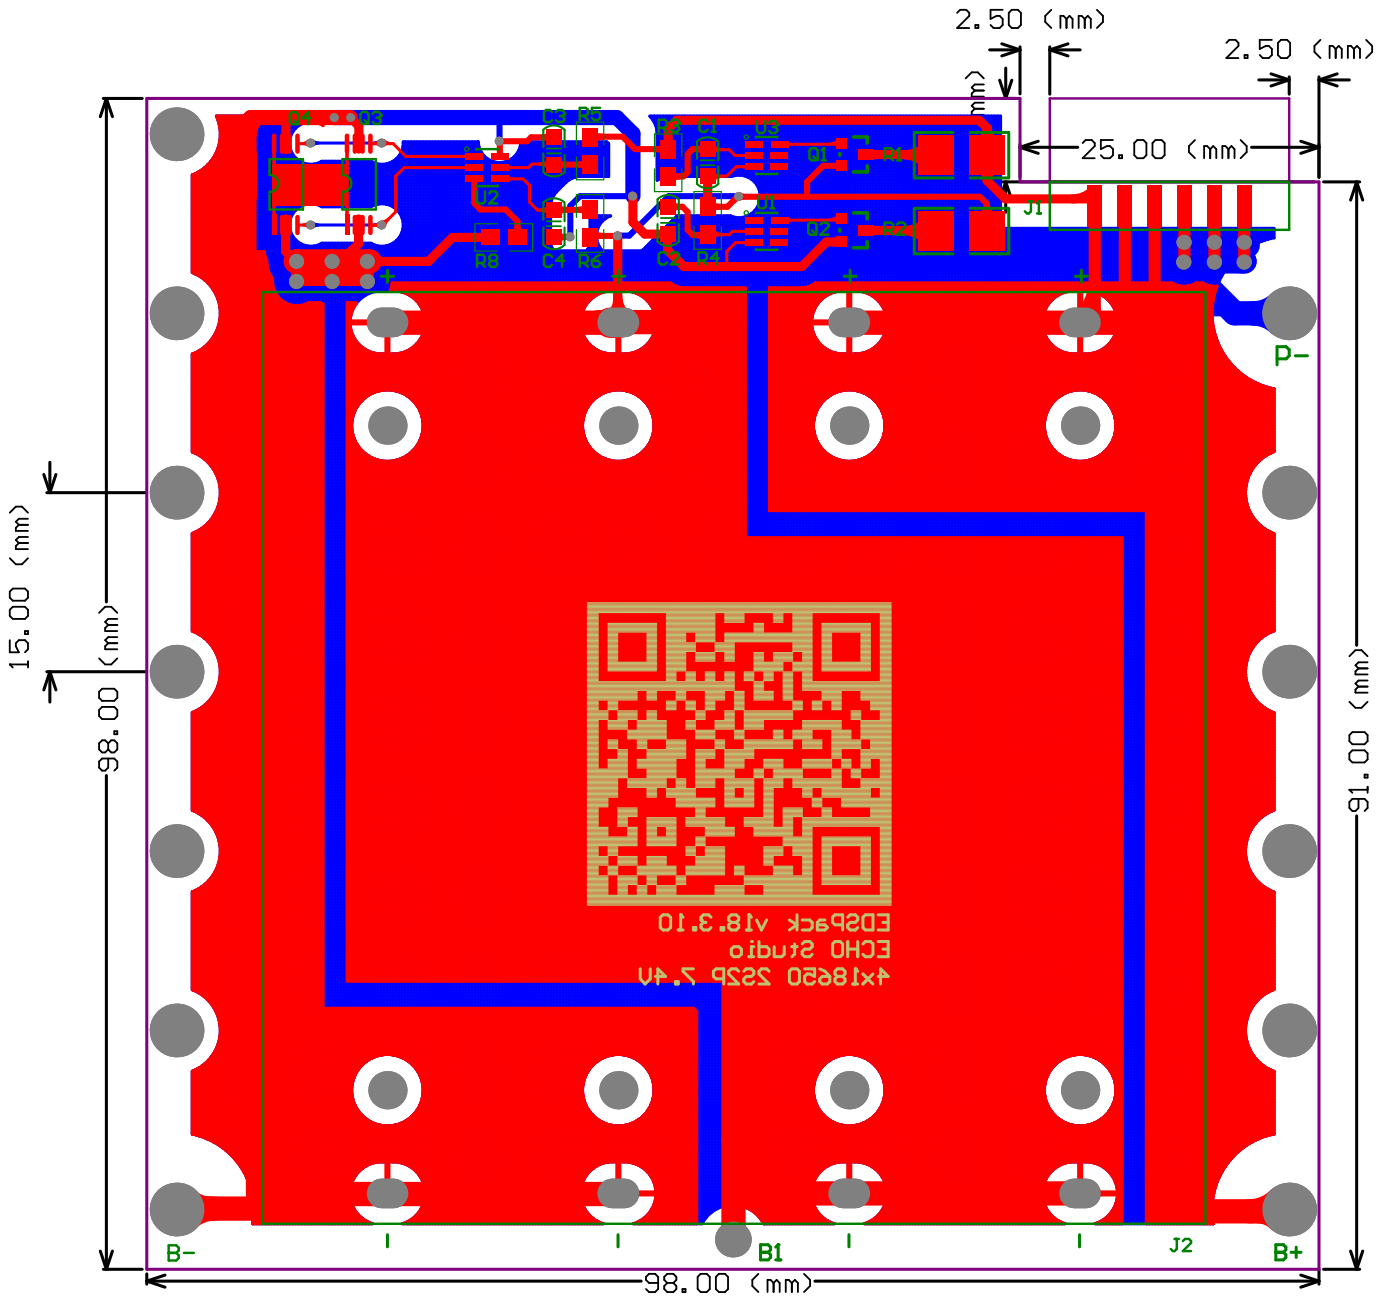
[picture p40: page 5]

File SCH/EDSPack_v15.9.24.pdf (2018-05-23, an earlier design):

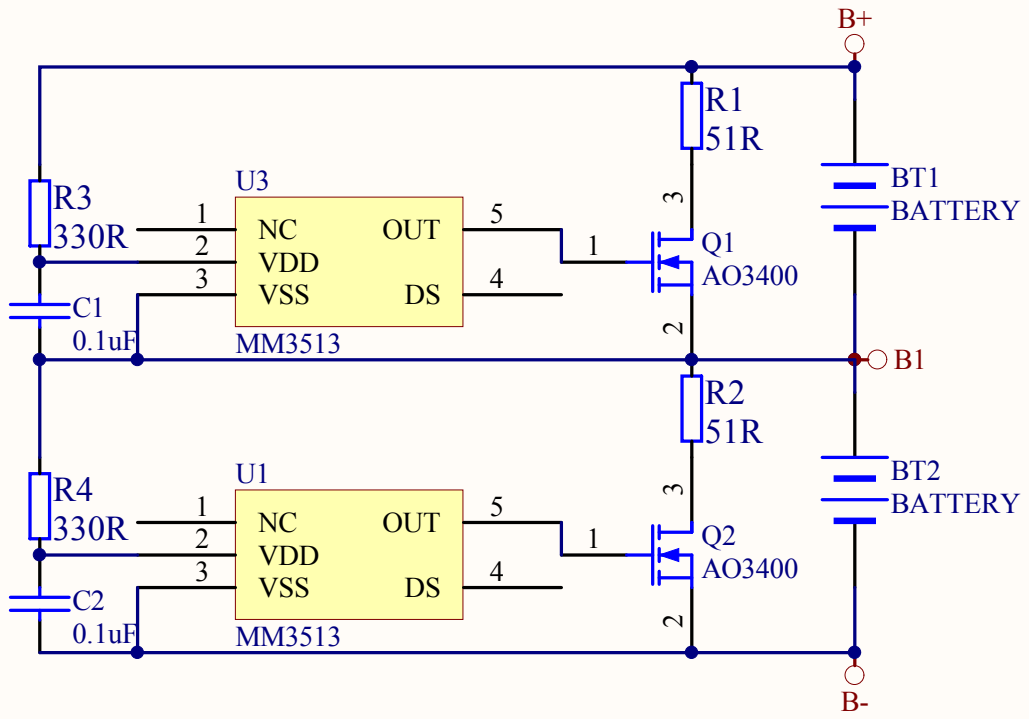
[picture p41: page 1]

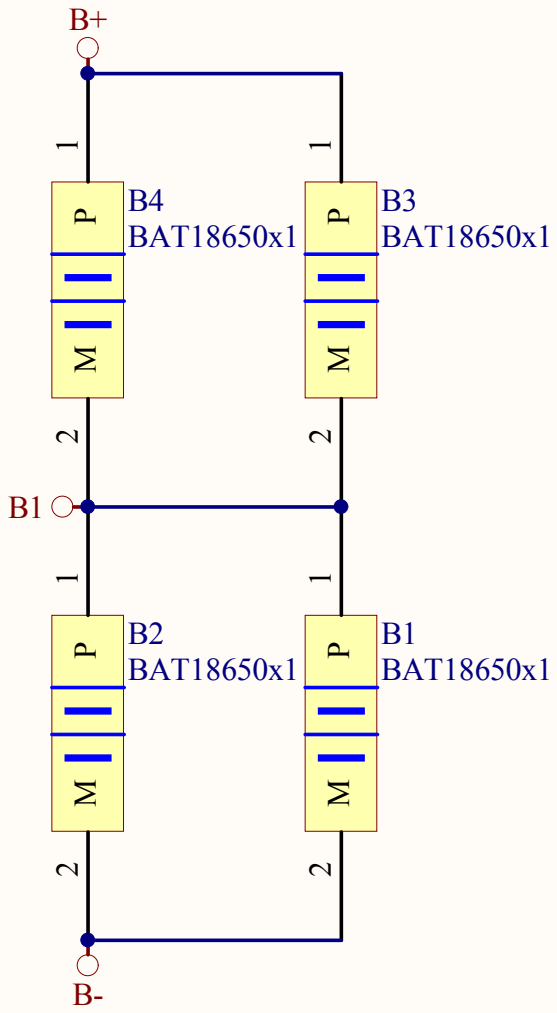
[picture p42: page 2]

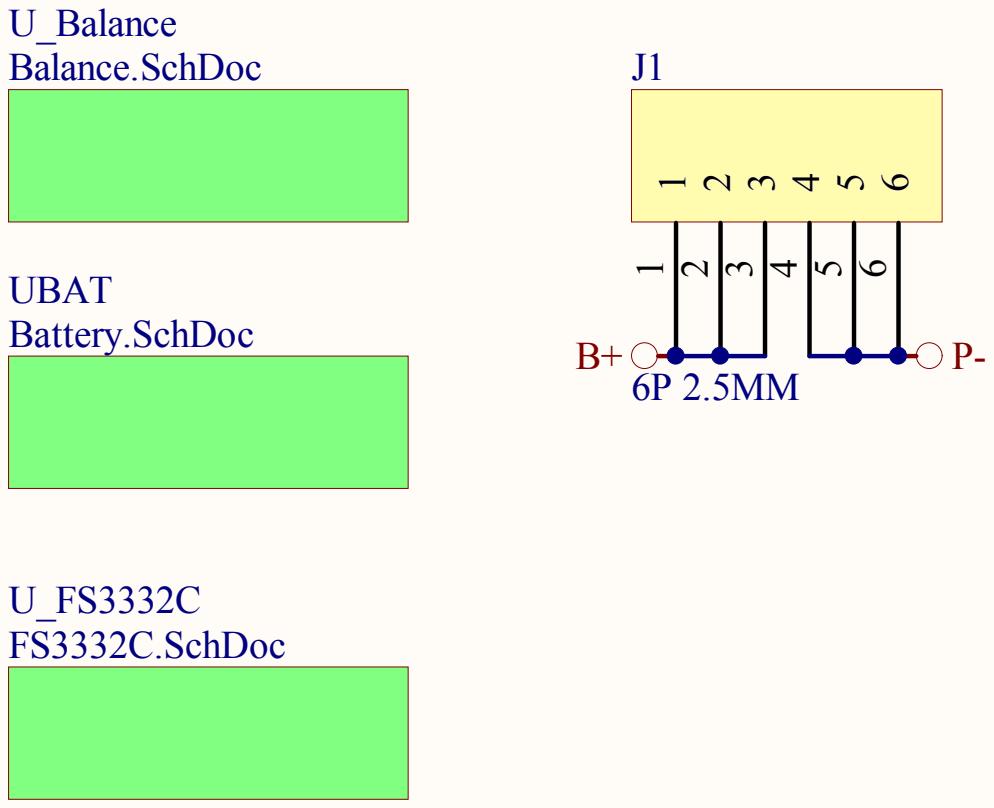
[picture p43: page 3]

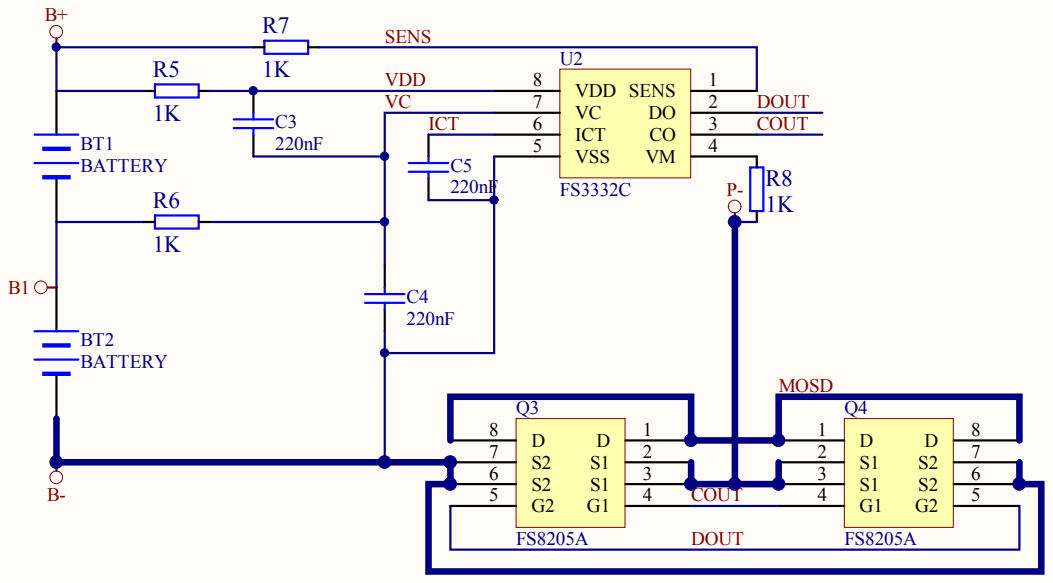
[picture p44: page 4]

C3 ICT | | ICT 6

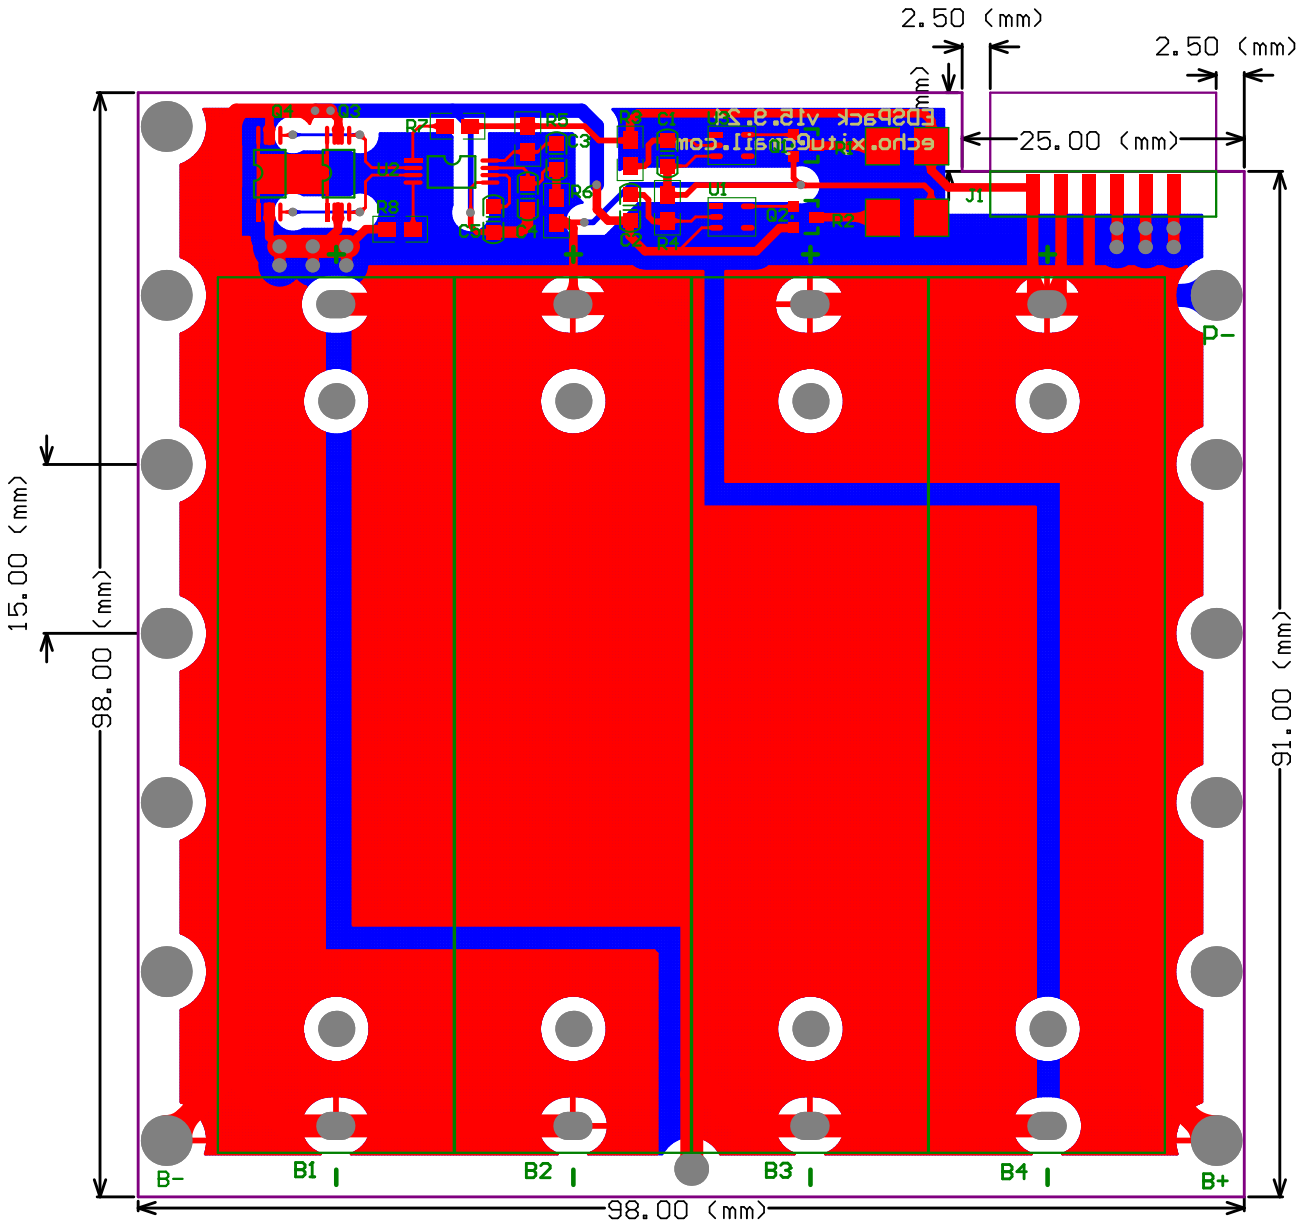
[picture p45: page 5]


Comment | Description | Designator | Footprint | LibRef | Quantity
BAT18650x1 | 1节电池盒 | B1, B2, B3, B4 | BAT18650x1 | BAT18650x1 | 4
0.1uF | 0.1uF 0805 50 V± 20% -25~+85 ℃ Y5V | C1, C2 | C0805 | C0805_104 | 2

6P 2.5MM | 6脚笔记本电池连 接器母座 | J1 | BAT_SOCKET_6 P_2.5MM | BAT_SOCKET_6 P_2.5MM | 1

AO3400 | N-Channel MOSFET | Q1, Q2 | SOT-23 | AO3400 | 2

FS8205A | Dual N-Channel Enhancement Mode MOSFET | Q3, Q4 | TSSOP-8 | FS8205A | 2

51R | 51Ω 2512 | R1, R2 | R2512-1210 | R2512-51R | 2
330R | 表贴电阻 330Ω 1/16W ±1% ± 200ppm | R3, R4 | R0805 | R0805-330R | 2

1K | 表贴电阻 1kΩ 1/16W ±1% ± 200ppm | R5, R6, R7, R8 | R0805 | R0805-1K | 4

MM3513 | Voltage Monitor IC for Li-ion Cell Balance | U1, U3 | SOT-23-5 | MM3513 | 2

FS3332C | 2节电池串联用电池保护U2 | | TSSOP-8 | FS3332C | 1

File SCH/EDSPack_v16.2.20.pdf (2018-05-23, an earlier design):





C3 ICT | | ICT 6


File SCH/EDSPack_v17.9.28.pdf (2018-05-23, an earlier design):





C3 ICT | | ICT 6


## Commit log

2018-05-23 add EDSPack schematic.
2019-02-16 add STOPack schematic.
2020-10-15 add Solidworks case from Matthew Pearce <mpea413@aucklanduni.az.nz>
    [EDSPackV18-3-10_Case_2019-05-11_1802.SLDPRT, EDSPackV18-3-10_Case_2019-05-11_1802.STL, OwonCaseSheath_2019-11-27.SLDPRT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]
2020-10-15 add solidworks case description.
